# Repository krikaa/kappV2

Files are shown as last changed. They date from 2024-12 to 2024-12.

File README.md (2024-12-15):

# Nutika laborikapi edasiarendus 

Continuation of development of a smart metal locker module, to make it openable with an ISIC card or through a web application.

Continuation by (TalTech Computers and Systems project 2024):

* Kristjan Kaal
* Daniel Erg 
* Hendrik Haabu

[Original 2023 project](https://github.com/siimtishler/kapp) by (TalTech Computers and Systems project 2023):

* Markus Visnapuu 
* Rannar Randmäe 
* Siim Tišler
* Markus Veersoo

## Full documentation (in Estonian)

[Targa laborikapi edasiarendus aruanne.pdf](https://github.com/krikaa/kappV2/blob/master/Targa%20laborikapi%20edasiarendus%20aruanne.pdf) \
The documentation contains details about the improvements, description of the product and instructions on how it should be put together.

## Introduction
This is the repo for course "IAS1420 Arvutite ja süsteemide projekt" at TalTech 2023. 
The goal of the project was to fix some software issues regarding the 2023 year project, add support for multiple lockers and put all the hardware in a single module that is both simpler to install and more universal.
This repo is only for more convenient code management and project is intended only as a study project.

## Hardware
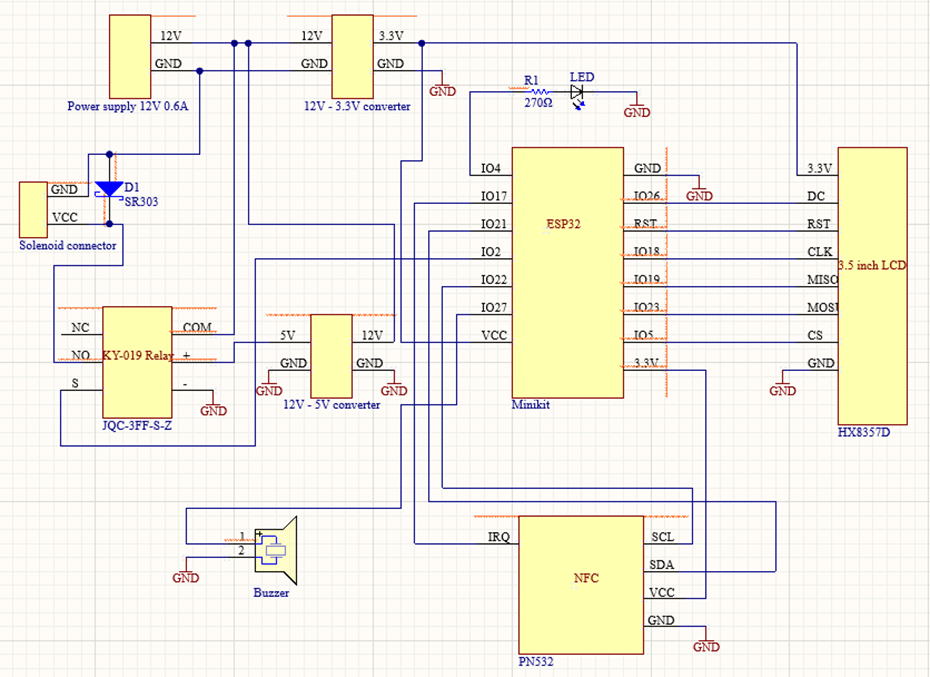
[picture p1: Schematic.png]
Schematic


## Installation
For fully setting up the device, the following has to be done:

1. Set up the web app:
* Clone the [web-interface](https://github.com/krikaa/kappV2-web-interface) submodule. 
* Set up a Google firebase with email-password user authentication and real-time database. 
* Add the rules found in database.rules.json to the Firebase database access rules. 
* Duplicate example.env, rename it to .env and fill the file in with the environment variables from your Firebase.
* Host the website on Firebase 
* Make the first admin account from Firebases management screen. 

2. Set up the electronics:
* Clone the [door-controller](https://github.com/krikaa/kappV2-door-controller/) submodule.
* Open the code in vscode and wait until necessary third-party libraries are installed through PlatformIO
* Duplicate FirebaseConfig.example.h, rename it to FirebaseConfig.h, and fill it in with your locker, Wi-Fi and Firebase details.
* Change PinConfig.h and platformio.ini to fit your hardware if necessary.
* Flash the code onto an ESP32.
* Build the [circuit](https://github.com/krikaa/kappV2/blob/master/Schematic.png) and test if everything works.

3. Set up the module:
* Print or manufacture the models found in the [3D-models](https://github.com/krikaa/kappV2/tree/master/3D-models) folder. 
NB! Be aware that many pieces require to be out of metal, or they will break!
* Put the module together by the instructions in the [documentation](https://github.com/krikaa/kappV2/blob/master/Targa%20laborikapi%20edasiarendus%20aruanne.pdf).
* Install the module on a locker by the instructions.

## Technologies Used
* C and C++ programming languages
* Firebase cloud service
* NFC reader library
* Visual Studio Code as an integrated development environment (IDE)
* SolidWorks for 3D CAD Design
* Git for version control

## Project layout/format
The project consists of two submodules:
* door-controller - Contains code for the ESP32 in the locker device, driving both the display and locking mechanism.
* web-interface - Contains code for the web interface, at https://nutikapp-v2.web.app

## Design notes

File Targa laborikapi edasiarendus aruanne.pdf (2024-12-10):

Tallinn 2024

TALLINNA TEHNIKAÜLIKOOL

Infotehnoloogia teaduskond

Daniel Erg 213407IACB
Hendrik Haabu 213440IACB
Kristjan Kaal 213423IACB

## Targa laborikapi edasiarendus

Arvutite ja süsteemide projekt

Juhendaja: Heiko Pikner

PhD

## Autorideklaratsioon

Kinnitame, et oleme koostanud antud projekti iseseisvalt ning seda ei ole kellegi teise

poolt varem kaitsmisele esitatud. Kõik töö koostamisel kasutatud teiste autorite tööd,

olulised seisukohad, kirjandusallikatest ja mujalt pärinevad andmed on töös viidatud.

Autorid: Daniel Erg, Hendrik Haabu, Kristjan Kaal

10.12.2024

## Lühendite ja mõistete sõnastik

RTOS | Real-time operating system, reaalaja operatsioonisüsteem
GPIO | General Purpose Input Output, üldkasutatav sisend-/väljundviik
JSON | JavaScript Object Notation, andmevahetusvorming
SPI | Serial Peripheral Interface, sünkroonse järjestiksuhtluse liidese standard
Wi-Fi | Sertifitseeritud IEEE 802.11 (https://et.wikipedia.org/wiki/IEEE_802.11) standardil põhinevad traadita kohtvõrgu klassi kuuluvad seadmed
NFC | Near-field communication, kontaktivaba lähiväljasidetehnoloogia
NO | Normally open, "tavapäraselt avatud“ väljaviik
SPA | Single-page application, üheleherakendus
HTML | Hypertext Markup Language, veebilehtede märgenduskeel
CSS | Cascading Style Sheets, küljendamisel kasutatav märgistuskeel
URL | Uniform recource locator, internetiaadress
SSID | Set Service Identifier, võrgu nimi traadita võrgus

## Sisukord

## Jooniste loetelu

Joonis 2. Nutikapi mooduli prototüüp paigaldatud esimesele laborikapi variandile...... 10

Joonis 10. Gerd Kanter Hoidiku sees ja fikseerimas Käepidet Ekraanikorpuse külge. . 15

Joonis 15. Käepide koos postkastiluku komplektiga ning tugipunkt Elektroonikakarbis

Joonis 17. Solenoid Elektroonikakarbis ning Käepideme ja keele asend kui kapp on

Joonis 29. Käepideme 90° liikumisulatuse funktsioon Gerd Kanteri ja Kimalase vahel.

Joonis 34. „BasicNavBar.vue“ administraatori vaates erinevate aknasuuruste puhul ... 38

Joonis 40. Ava Ekraanikorpusest tulevate juhtmete jaoks ning prototüüp koos juhtmega.

Joonis 41. Prototüübiks kasutuses olnud Käepide ja esimese valmis komponendi jaoks

Joonis 43. Detailid kolmanda valmis komponendi jaoks ning pistikud Elektroonikakarbi

Joonis 45. Ühe testitud laborikapi jaoks vajaminevad Tuulerõuged mooduli

## 1 Sissejuhatus

Käesolev töö on edasiarendus targa laborikapi projektist [1]. Tallinna Tehnikaülikoolis

on laialdaselt kasutusel erinevat tüüpi laborikapid ja nii mõnelegi on soovitud paigaldada

tark süsteem. Kuna NFC-l põhinevate lukusüsteemide kasutamise populaarsus on ajaga

suurenenud, siis on teema aktuaalne [2].

Projekti ülesanne on arendada edasi varem tehtud tarka laborikappi. Eelneva töö

puudusteks olid tarkvaras mitme kapi toe puudumine ja lahenduse realisatsioon mitme

moodulina ehk mitme füüsilise tükina, mis muutis paigaldamise tülikaks, ja kapi

originaalse riivi eemaldamise vajadus. Eelneva targa laborikapiga oli ka see probleem, et

ühel hetkel seda ei saanud enam kaardiga avada ja mure oli ka see, et kui vool ära kadus,

siis oli kapi avamine samuti üsna ebamugav. Seega antud töö eesmärk on ehitada

võimalikult kompaktne, soodne, universaalne ja lihtsasti paigaldatav moodul, mis

muudaks metallist laborikapi targaks, kusjuures tarkvara peab võimaldama mitme kapi

kasutust. Lahendus peab kasutama ka kapi originaalset riivi ja voolu kadumisel peab kapp

olema avatav ka võtmega. Eesmärk on muuta ka kapp jälle kaardiga avatavaks.

Töö hõlmab endas nii riistvara, tarkvara, mehaanikat kui ka modelleerimist. Terve

projekti vältel tegeleti nende kõikide mainitud osadega pidevalt, kuid alguses oli suurem

rõhk modelleerimisel ja riistvaral. Töö peatükid on jaotatud samasugusel põhimõttel:

alguses selgitatakse lukusüsteemi kogu mehaanika ja modelleerimisega seonduvat poolt,

siis selgitatakse riistvara kasutust ja elektriskeemi ning lõpuks mõtestatakse lahti

tarkvaraline osa, sealhulgas püsivara ja veebirakendus. Viimasteks peatükkideks on

mooduli paigaldamise juhend ja edasiarenduse võimalused.

## 2 Mehaanika

Nutikapi mooduli loomiseks modelleeriti esialgu prototüüp ning hiljem lõplik toode.

Prototüüp prinditi plastikust ning seda kasutati kahel erineval laborikapil testimiseks.

Katsete käigus tuvastatud puudujääkide tõttu tuli muuta nii detailide mõõtmeid kui ka

modelleerida osad mudelid ümber eesmärgiga need hiljem metallist toota, sest need ei

pidanud kapi hoovamehhanismi liigutades pingele vastu. Prototüübi peatükk kirjeldab

esialgse mooduli jaoks ehitatud detaile, nende probleeme ja funktsionaalsust ning lõpliku

mooduli peatükis on välja toodud muudatused toote viimase versioonini jõudmiseks.

Kõik detailid on modelleeritud 3D projekteerimistarkvaras Solidworks.

### 2.1 Prototüüp

Prototüübi jaoks modelleeriti 9 detaili, mille nimed on Ekraanikorpus, Ekraanikorpuse

Kaas, Käepide, IKEA Laud, Gerd Kanter, Hoidik, Naagelvärk, Elektroonikakarp ja

Elektroonikakarbi Kaas.

Lisaks soetati ehitusmaterjali poodidest M1x10 mm, M3x16 mm ja M4x90 mm suurusega

polte, 3.5x9.5 mm suurusega kruvisid, 3/4 tolli suurusega kontramutter ja pikkvint,

nelinurkne M4 mutter, M4 suurusega võllikrae ja postkastiluku komplekt.

Joonisel 1 on näha prototüübi modelleeritud detailid kokkupanduna ning joonistel 2 ja 3

on näha prototüübi paigaldust kahele laborikapi variandile.

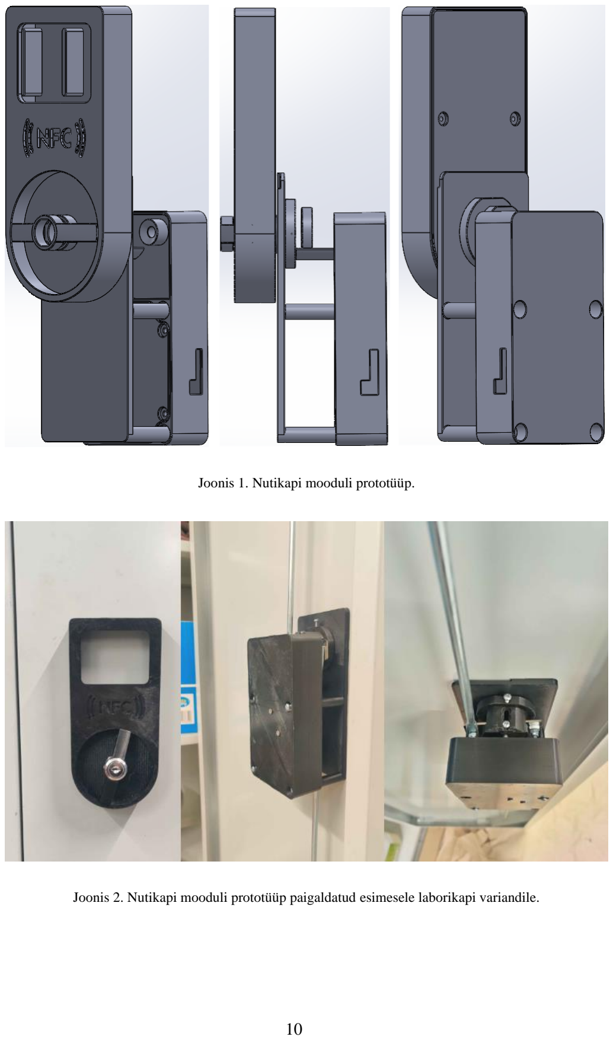
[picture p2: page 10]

Joonis 1. Nutikapi mooduli prototüüp.

Joonis 2. Nutikapi mooduli prototüüp paigaldatud esimesele laborikapi variandile.

Joonis 3. Nutikapi mooduli prototüüp paigaldatud teisele laborikapi variandile.

### 2.1.1 Mooduli väline korpus

Mooduli väline korpus on laborikapist väljapoole jääv ekraani ja NFC moodulit hoiustav

komponent (vt Joonis 2 ja 3, vasakpoolne pilt). See koosneb modelleeritud Käepidemest,

Ekraanikorpusest ja Ekraanikorpuse Kaanest ning ehitusmaterjalide poest soetatud

postkastilukust, kolmest 3.5x9.5 mm suurusega kruvist ja 3/4 tolli suurusega pikkvindist.

Joonisel 4 on näha välise korpuse mudeleid nii eest kui ka tagant.

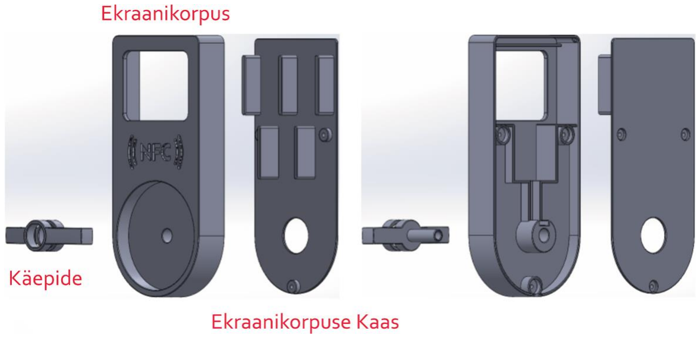
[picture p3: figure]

Joonis 4. Mooduli välise korpuse detailid.

Ekraanikorpuse sees olev suurem ristkülikukujuline süvend on mõeldud puutetundliku

ekraani jaoks ning väiksem NFC mooduli jaoks. Korpuse kaanel on viis väljaulatuvat

risttahukat, mille eesmärgiks on hoida ekraani ja NFC moodulit korpuse vastas. Kaanel on ka kolm silindrikujulist jalga, mis sobituvad korpusel olevatesse analoogsetesse

süvenditesse ning need kinnitatakse väljastpoolt kolme 3.5x9.5 mm suuruse kruviga.

Joonisel 4 vasakult teisel detailil ehk Ekraanikorpusel on ka näha ringikujulist süvendit,

mis on mõeldud Käepideme pöörlemiseks ning NFC logo, mille mudel on võetud eelmise

laborikapi mooduli versiooni tegijatelt [1]. Käepideme toru ulatub läbi Ekraanikorpuse

kapi sisse.

### 2.1.2 Mooduli kinnitus kapi uksele

Mooduli kinnitus kapi uksele on kapist sissepoole jääv komponent, mille eesmärk on

hoida Ekraanikorpust ja Elektroonikakarpi kapi ukse küljes. See koosneb modelleeritud

IKEA Lauast ning selle juures mängib olulist rolli ka Ekraanikorpuse tagant väljaulatuv

jäme silinder. Lisaks on kasutusel 3/4 tolline kontramutter ja pikkvint ning neli M3x16

mm polti. Joonisel 5 on näha kinnituse modelleeritud detailid.

Joonis 5. Mooduli kinnituse detailid.

IKEA Laua jalgade külge kinnitub Elektroonikakarp ning seda hoiavad jalgade küljes neli

M3x16 mm polti. Laud jääb Ekraanikorpusest allapoole, kuna mõlemal testitud

laborikapil jäi sisemine riiul muidu Elektroonikakarbile ette. Ekraanikorpuse ja IKEA

Laua vahele jääb laborikapi uks. Eemaldades ukse originaalse käepideme, jääb selle

asemele ava ning läbi ava ja IKEA Laual oleva suure ümmarguse augu paigaldatakse

Ekraanikorpus tänu tema küljes olevale jämedale silindrile. Prototüübi testimiseks saeti

3/4 tolline pikkvint sobivaks suuruseks ning kinnitati silindri ümber, mistõttu sai

kontramutri abil suruda IKEA Laua ja Ekraanikorpuse tugevalt ukse külge (vt Joonis 6).

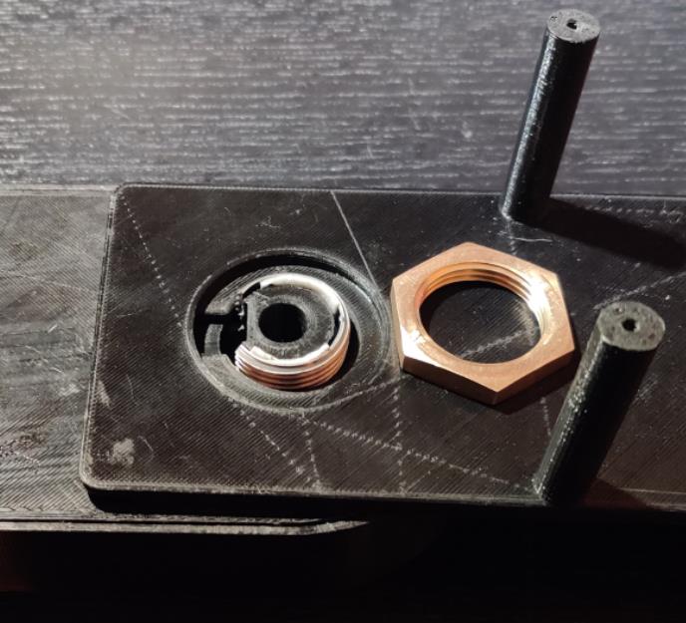
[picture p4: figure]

Joonis 6. Pikkvint Ekraanikorpuse silindri küljes.

### 2.1.3 Elektroonikakarp

Elektroonikakarp on IKEA Laua külge kinnituv solenoidi ja elektriskeemi hoiustav

komponent, mis koosneb modelleeritud karbist ja selle kaanest (vt Joonis 7). Kaane

kinnitamiseks on kasutusel neli 3.5x9.5 mm kruvi.

Joonis 7. Elektroonikakarbi detailid.

Elektroonikakarbi külje peal on avad 12 V toitepistiku ning ekraani ja NFC mooduli

küljest tuleva 15 viiguga juhtme pistiku jaoks. Karbi üleval servas oleva silindri ning

solenoidi täpsema asetuse ja eesmärgi kohta on kirjas kapi lukustamise mehhanismi

alapeatükis.

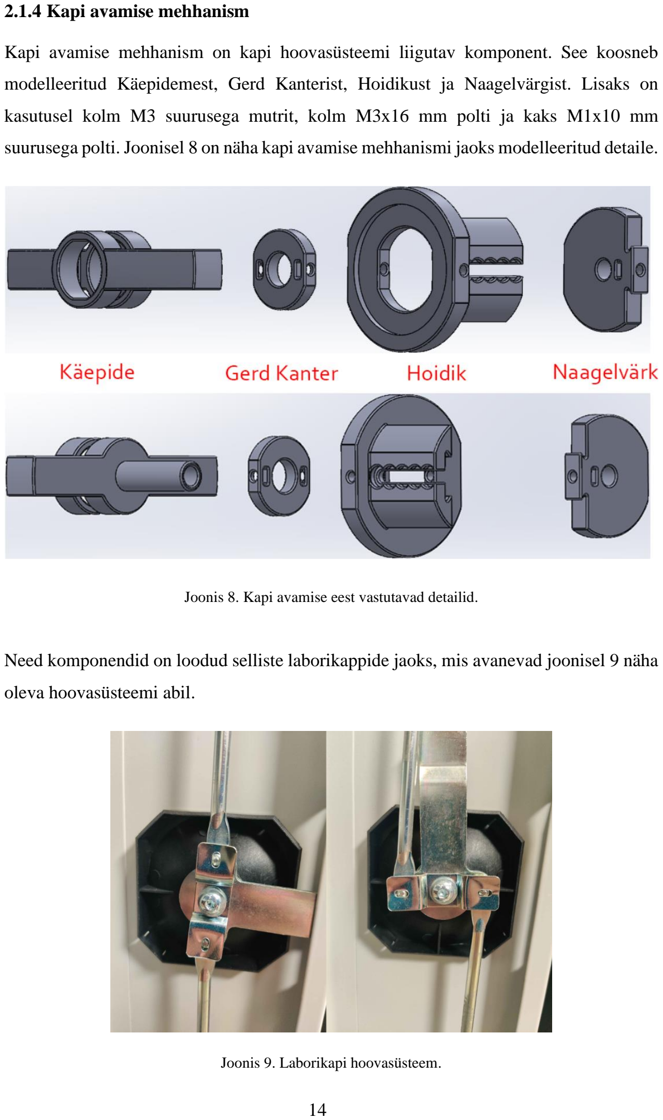
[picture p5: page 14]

### 2.1.4 Kapi avamise mehhanism

Kapi avamise mehhanism on kapi hoovasüsteemi liigutav komponent. See koosneb

modelleeritud Käepidemest, Gerd Kanterist, Hoidikust ja Naagelvärgist. Lisaks on

kasutusel kolm M3 suurusega mutrit, kolm M3x16 mm polti ja kaks M1x10 mm

suurusega polti. Joonisel 8 on näha kapi avamise mehhanismi jaoks modelleeritud detaile.

Joonis 8. Kapi avamise eest vastutavad detailid.

Need komponendid on loodud selliste laborikappide jaoks, mis avanevad joonisel 9 näha

oleva hoovasüsteemi abil.

Joonis 9. Laborikapi hoovasüsteem.

Gerd Kanter kinnitub kahe M1x10 mm suuruse poldiga Käepideme toru külge ja kahe

M3x16 mm poldiga Hoidiku külge. Tema küljes olevate piklike avade sisse kinnitati

eraldi M3 mutrid, mis olid mõeldud ajutiste keermetena. Gerd Kanteri eesmärk on keerata

Hoidikut ning vältida Käepideme välja kukkumist Ekraanikorpusest (vt Joonis 10).

Joonis 10. Gerd Kanter Hoidiku sees ja fikseerimas Käepidet Ekraanikorpuse külge.

Hoidiku eesmärk on keerata laborikapi hoovasüsteemi ning sellele kinnitati Naagelvärk

ühe pooleks saetud M3x16 mm poldiga hoovasüsteemi paremaks fikseerimiseks (vt

Joonis 11).

Joonis 11. Hoovasüsteem Hoidiku ja Naagelvärgi vahel.

Hoidiku all on viis erinevat süvendit M3x16 mm poldi kinnitamiseks. Nende abil on

võimalik Naagelvärgi kaugust kapi hoovasüsteemist reguleerida, kuna erinevatel

laborikappidel võib süsteem olla kas teistsuguse kujuga või asetseda kapi seinast

kaugemal või lähemal. Ka Naagelvärgile oli prototüübi jaoks modelleeritud piklik auk

ajutise mutri kinnitamiseks. Hoidikut ja Naagelvärki altvaates on näha joonisel 12.

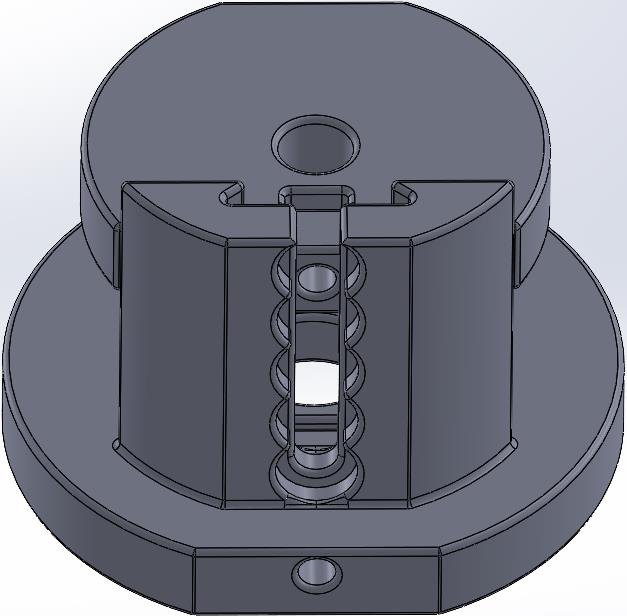
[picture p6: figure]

Joonis 12. Hoidik ja Naagelvärk altvaates.

Kinnises asendis toimivad kapi hoovasüsteemist välja ulatuvad pikad vardad riividena

ning hoiavad ust kapi ülemise ja alumise serva küljes kinni. Keerates käepidet 90°

päripäeva, liigutab Hoidik hoovasüsteemi lahtisesse asendisse ning kapp avaneb.

Hoovasüsteem kinnises asendis on näha joonisel 13 vasakul pool ja lahtises asendis

paremal pool.

Joonis 13. Kapi avamise liigutus.

Kapi sulgemiseks tuleb keerata käepidet tagasi 90° vastupäeva.

### 2.1.5 Kapi lukustamise mehhanism

Kapi lukustamise mehhanism on kapi ukse lukustamise loogikat käsitlev komponent.

Lisaks avamise mehhanismi komponendile, koosneb lukustamise komponent

postkastiluku komplektist, ühest M4x90 mm poldist ning võllikraest, nelinurksest mutrist

ja seibist, mis on kõik M4 suurusega. Riistvarast on kapi lukustamisel oluline roll

solenoidil ja NFC moodulil.

Pannes kõik siiamaani käsitletud komponendid tagasi kokku, on märgata, et läbi kogu

mooduli on jäetud 6 mm diameetriga ava (vt Joonis 14, sinine täpp).

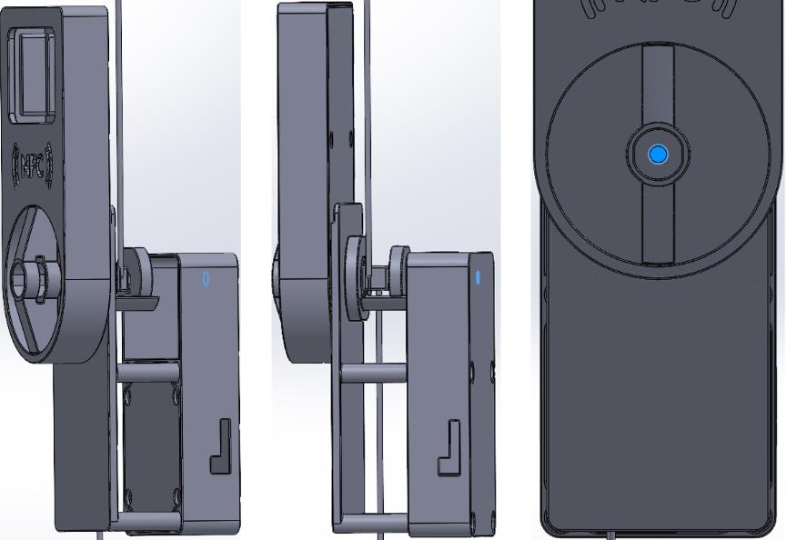
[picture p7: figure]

Joonis 14. Nutikapi moodulit läbiv ava.

Kogu ava läbib M4x90 mm polt, mis on ühe otsaga kinnitatud Käepideme sees oleva

postkastiluku külge ja teine ots toetub Elektroonikakarbi üleval servas oleva jämeda

silindri sisse (vt Joonis 15).

Joonis 15. Käepide koos postkastiluku komplektiga ning tugipunkt Elektroonikakarbis

Poldil on Elektroonikakarbi poolsel otsal keermed maha lihvitud ning teisel pool pea ära

lõigatud. Lihvitud otsale puuriti tilluke süvend, millesse kinnitati esimesena väikse

kruviga võllikrae ja teiseks postkastiluku keel, mille sees on sobivaks suuruseks lihvitud

nelinurkne mutter eesmärgiga kanda jõudu Käepidemelt keelele. Järgmisena kinnitati

poldile seib, mis hoiab keelt võllikrae vastas ning lõpus liimiti detailid tugeva kiirliimiga

kokku (vt Joonis 16).

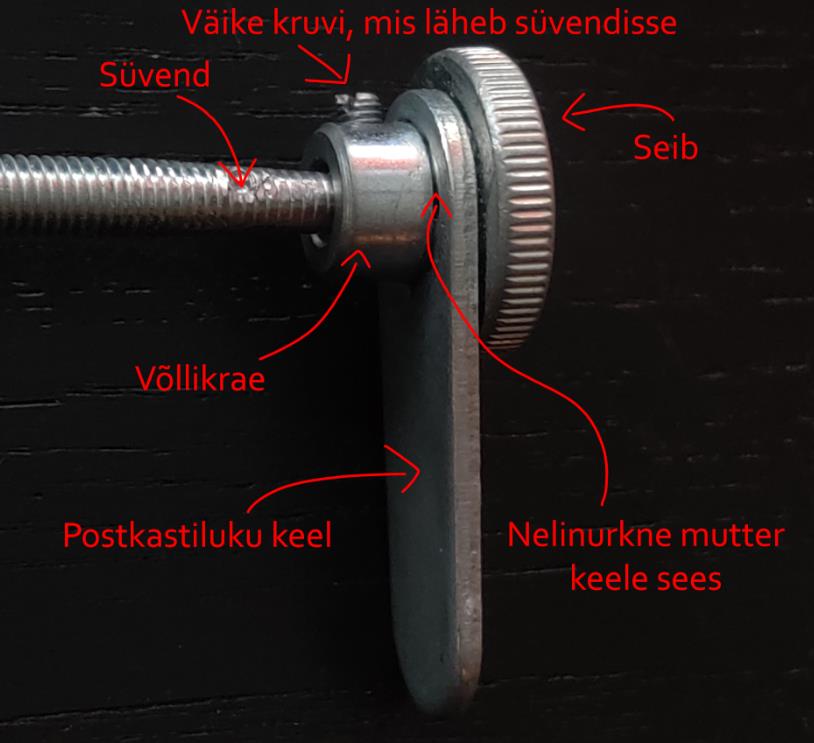
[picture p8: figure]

Joonis 16. Postkastiluku keele kinnitus poldi otsas.

Kuna postkastiluku keel on Käepideme küljes, ongi tema eesmärgiks lukustada kapp ehk

blokeerida Käepideme liikumine. Keele liikumise takistamiseks on kasutusel solenoid.

Joonisel 17 on näha solenoidi asukoht Elektroonikakarbis ning Käepideme ja keele asend

kui kapp on lukustatud.

Joonis 17. Solenoid Elektroonikakarbis ning Käepideme ja keele asend kui kapp on lukustatud.

Kuna kapi hoovasüsteemi liigutamiseks avatud asendisse tuleb käepide keerata 90°

päripäeva, on see hetkel piiratud, sest solenoid takistab keele liikumist. Selleks, et

Käepide liigutada, on esimeseks variandiks asetada ISIC kaart NFC mooduli vastu,

mistõttu läheb solenoidi keel alla ja Käepide on võimalik keerata. Prototüübil on võimalik

keerata ka Käepide täisnurga võrra vastupäeva, kuid lõplikul tootel on see takistatud. Kapi

lukustamiseks tuleb Käepide keerata tagasi 90° vastupäeva ning postkastiluku keel liigub

sujuvalt üle solenoidi keele ja jõuab tagasi suletud asendisse (vt Joonis 18).

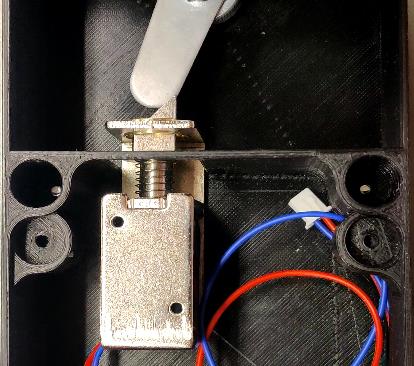
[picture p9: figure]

Joonis 18. Postkastiluku keele liikumine üle solenoidi keele.

Teine variant kapi avamiseks on keerata võtmega postkastilukku. Sellisel juhul pöörleb

keel 90° vastupäeva, mistõttu on võimalik taaskord Käepidet keerata täisnurga võrra

päripäeva (vt Joonis 19).

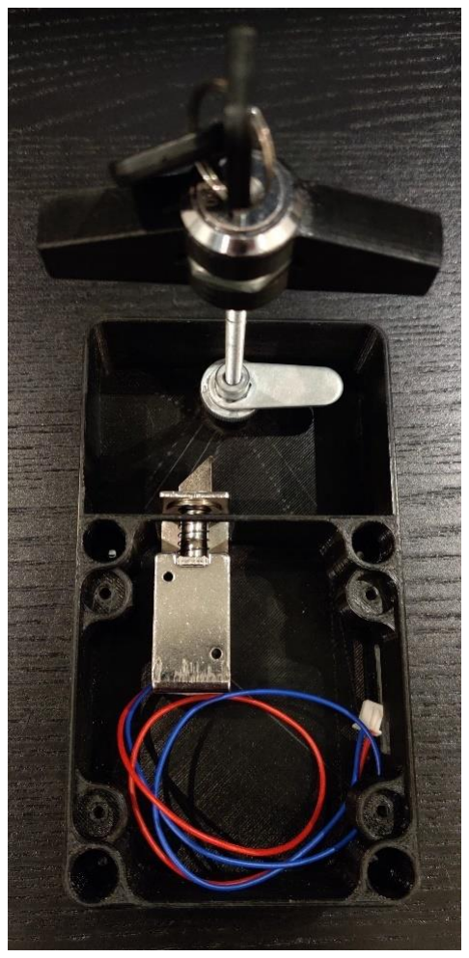
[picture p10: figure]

Joonis 19. Keele keeramine võtmega 90° võrra vastupäeva.

Kuna Käepidemest väljaulatuv polt pole kuidagi ühendatud Gerd Kanteri, Hoidiku ega

hoovasüsteemiga ning saab neid läbides vabalt pöörelda, siis võtmega poldi ja keele

keeramine ei liiguta Hoidikut ega Käepidet.

### 2.2 Lõplik moodul

Prototüübi testimisel laborikappidel oli põhiliseks probleemiks plastikdetailide nõrkus –

hoovasüsteemi liigutavad ja moodulit kapi küljes hoidvad komponendid läksid mõõduka

pinge all katki. Lisaks tuli muuta mõnde komponenti mõõtmeid. Seetõttu otsustati

modelleerida osad detailid eesmärgiga need lõpuks metallist toota ning mõelda välja

viisid, kuidas need plastikdetailide külge kinnitada. Kuna puudus metalliprinter, ei olnud

võimalik uusi komponente toota, mistõttu neid ei testitud kordagi laborikappidel.

Lõplik toode koosneb 12 modelleeritud detailist nimedega Ekraanikorpus,

Ekraanikorpuse Kaas, Kimalane, Käepide, Toru, IKEA Laud, Mutter, Gerd Kanter,

Hoidik, Naagelvärk, Elektroonikakarp ja Elektroonikakarbi Kaas.

Kimalane, Toru, Mutter, Gerd Kanter, Hoidik ja Naagelvärk on mõeldud tootmiseks

metallist, ülejäänud plastikust.

Joonis 20. Targa laborikapi mooduli lõppversioon.

### 2.2.1 Mooduli välise korpuse muudatused

Uue mooduli väline korpus koosneb lisaks Käepidemele, Ekraanikorpusele ja

Ekraanikorpuse Kaanele ka Kimalasest ning Torust. Kimalane on metallist detail, mis

asendab prototüübil olnud jämeda silindri ning eraldi pikkvindist saetud keermed. Toru

on metallist detail, mis asendab eelneva Käepideme plastikust toru. Lisaks muudeti

ekraaniava suurust, kuna vahepeal võeti kasutusele uus ekraanimoodul, ning korpusele

lisati juurde Tuulerõuged ehk üheksa M3 poldi süvendit, millest on täpsemalt kirjas

mooduli kapile paigaldamise peatükis. Joonisel 21 on näha paarides vastavalt uut ja vana

korpust.

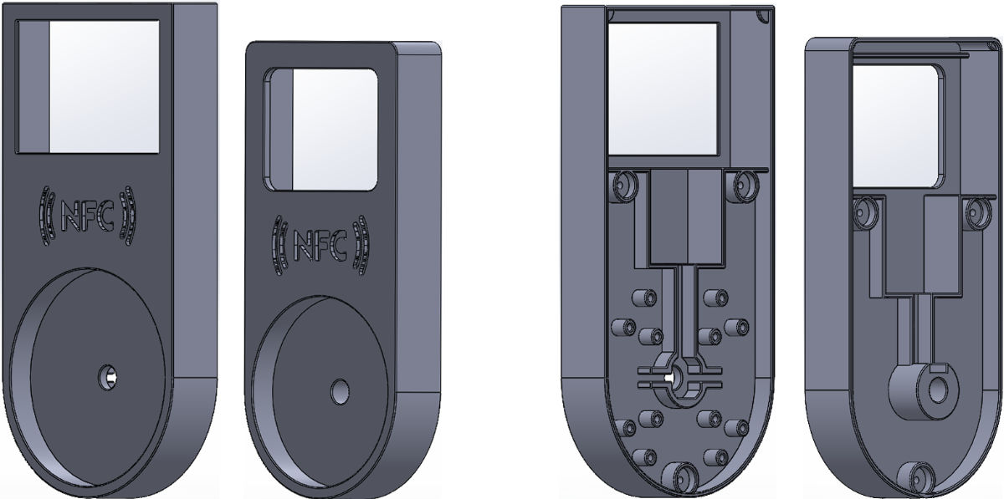
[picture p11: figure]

Joonis 21. Uue ja vana Ekraanikorpuse võrdlus eest ja tagant.

Kuna uus ekraan oli pikema diagonaaliga, muudeti kogu korpust suuremaks. Lisaks on

tagant näha, kuidas jäme silinder on asendatud uue Kimalase pesaga. Kimalast ning selle

asetsemist süvendis on näha joonisel 22.

Joonis 22. Kimalane ja selle asetsemine Ekraanikorpuse süvendis.

Kimalane kinnitub süvendisse kahe M3x16 mm poldiga ning tema tööpõhimõte on

täpsemalt lahti seletatud mooduli uuendatud kinnituse ja uuendatud kapi avamise

mehhanismi alapeatükkides.

Kuna eelmine plastikust Käepideme toru läks esimesena prototüübi testimisel pooleks,

asendati see eraldi metallist detailiga, mida on koos uue Käepideme mudeliga näha

joonisel 23.

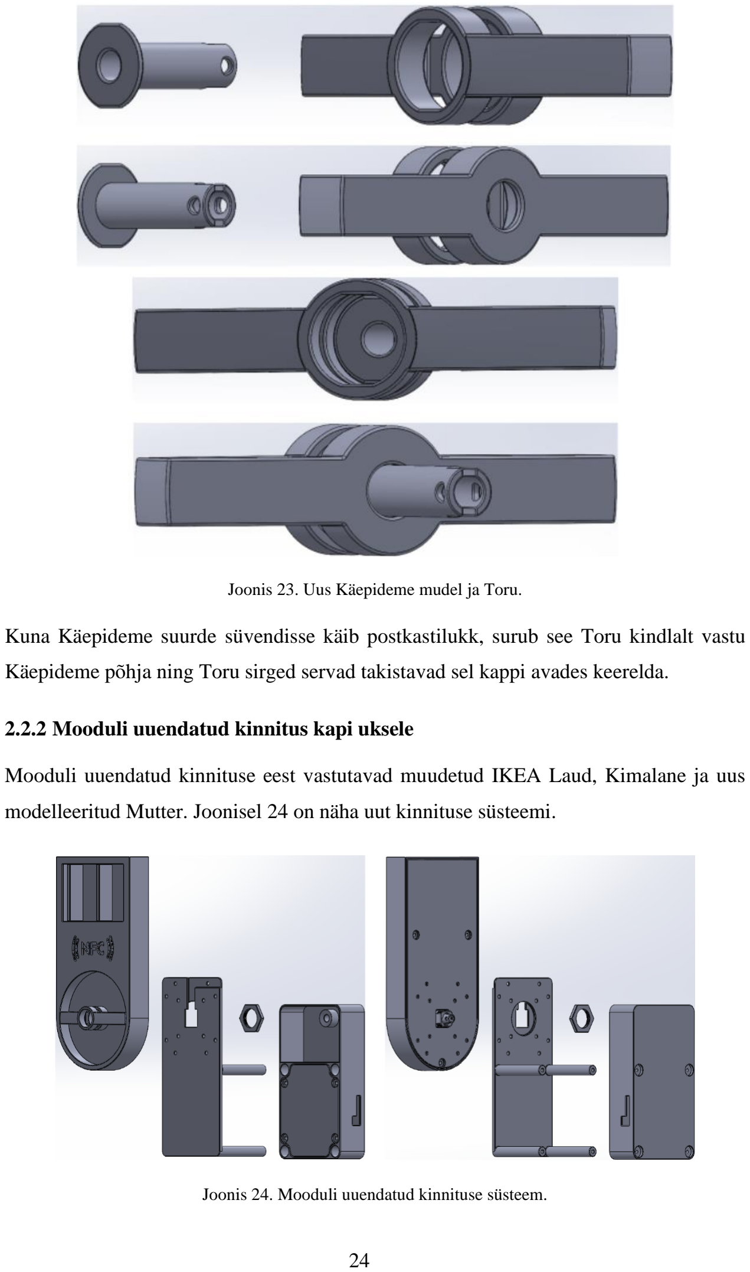
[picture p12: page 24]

Joonis 23. Uus Käepideme mudel ja Toru.

Kuna Käepideme suurde süvendisse käib postkastilukk, surub see Toru kindlalt vastu

Käepideme põhja ning Toru sirged servad takistavad sel kappi avades keerelda.

### 2.2.2 Mooduli uuendatud kinnitus kapi uksele

Mooduli uuendatud kinnituse eest vastutavad muudetud IKEA Laud, Kimalane ja uus

modelleeritud Mutter. Joonisel 24 on näha uut kinnituse süsteemi.

Joonis 24. Mooduli uuendatud kinnituse süsteem.

Peamine erinevus vana süsteemiga on IKEA Lauale lisandunud Tuulerõuged, mis on ka

Ekraanikorpuse Kaanel, ning Laua suure ava kuju muutmine ristkülikukujuliseks. Kuna

vana Ekraanikorpuse jämedat silindrit asendab nüüd Kimalane, mis on samuti

ruudukujuline, püsib mooduli kapisisene osa alati välise korpusega paralleelselt. Lähemat

vaadet Kimalase kinnitumisest IKEA Laua külge on näha joonisel 25.

Joonis 25. Kimalase kinnitumine IKEA Laua külge.

Lisaks modelleeriti juurde spetsiaalselt nutikapi moodulile sobiv Mutter, kuna

ehitusmaterjalide poest sobivat mutrit ei leitud.

### 2.2.3 Elektroonikakarbi muudatused

Elektroonikakarpi muudeti lõplikus moodulis võrreldes teiste komponentidega väga

vähe. Vähendati karbi taga olevate kruvisüvendite sügavust ning tehti postkastiluku poldi

tugipunkti silindrit sügavamaks. Vana ja uue elektroonikakarbi erinevused on näha

joonisel 26.

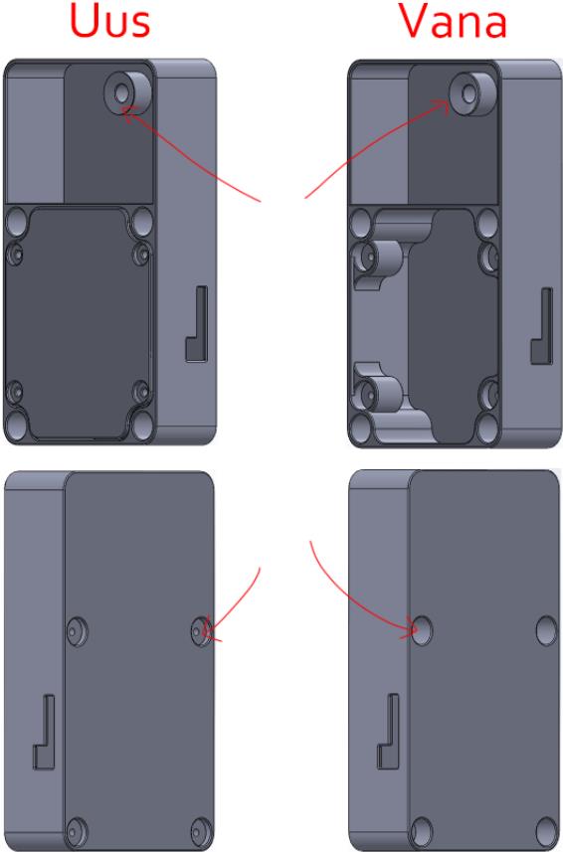
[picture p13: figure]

Joonis 26. Elektroonikakarbi muudatused.

### 2.2.4 Uuendatud kapi avamise mehhanism

Enamik muudatusi võrreldes prototüübi detailidega tehti kapi avamise mehhanismi

juures. Uus mehhanism koosneb Käepidemest, Torust, Kimalasest, Gerd Kanterist,

Hoidikust ja Naagelvärgist. Esiteks on iga mudel nüüd mõeldud tootmiseks metallist,

teiseks muudeti iga detaili kuju ja suurust ning kolmandaks mängib olulist rolli kapi

avamisel ka Kimalane.

Joonis 27. Kapi uuendatud avamise mehhanismi detailid.

Hoidik ja Naagelvärk jäid põhimõtteliselt samasuguseks. Naagelvärgil eemaldati ajutine

auk mutri jaoks ning muudeti veidike nii Naagelvärgi kui ka Hoidiku kuju ja suurust.

Peamine muudatus on Toru kinnitumine Gerd Kanteri külge ning uus Käepideme 90°

liikumisulatuse funktsioon Gerd Kanteri ja Kimalase vahel. Prototüübil oli Käepideme

toru kinnitatud Gerdi külge kahe M1x10 mm poldiga, kuid need olid liiga peenikesed

ning läksid hoovamehhanismi keerates lõpuks pooleks. Uuel Kanteril on kaks M3 kruvi

auku ning külgede peale on jäetud süvendid, et kruvi pead mahuksid Hoidiku alla.

Joonisel 28 on näha Toru, Gerd Kanterit ja Hoidikut kokku ühendatuna.

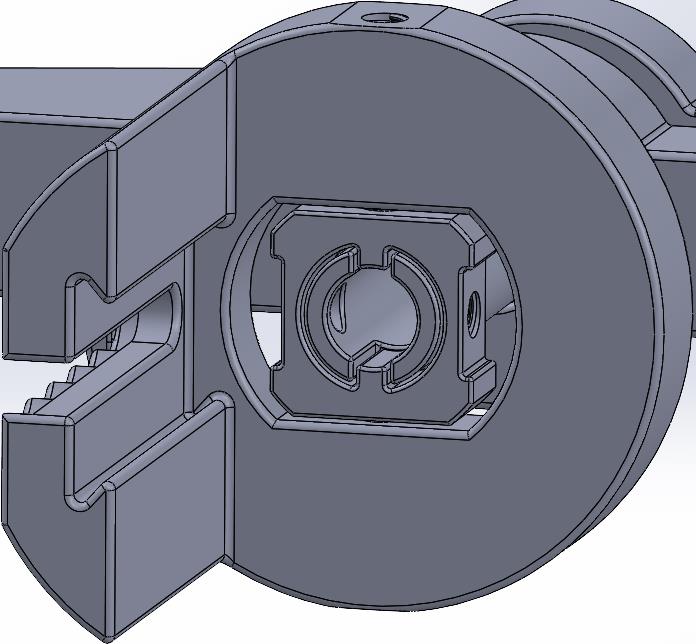
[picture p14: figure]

Joonis 28. Toru, Gerd Kanter ja Hoidik kokku ühendatuna.

Uue Gerd Kanteri ja Kimalase vahelise 90° Käepideme liikumisulatuse funktsiooni jaoks

modelleeriti Gerdile väike vars, mis libiseb Kimalases oleva kaare sees (vt Joonis 29,

sinised märgistused).

Joonis 29. Käepideme 90° liikumisulatuse funktsioon Gerd Kanteri ja Kimalase vahel.

### 2.2.5 Kapi lukustamise mehhanismi muudatused

Analoogselt Elektroonikakarbi komponendiga, ei muudetud eriti palju kapi lukustamise

mehhanismi, kuna see töötas vigadeta. Ainus muudatus oli käepidemes postkastiluku

mutri augu läbimõõdu suurendamine, kuna prototüübi mudelil oli see liiga väike ning

seda tuli käsitsi suuremaks lihvida.

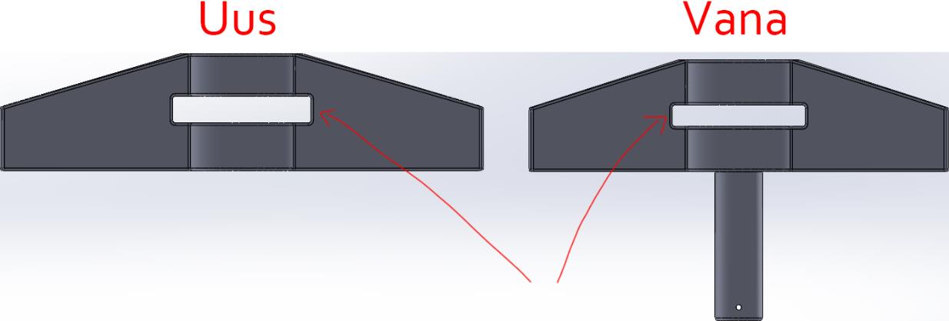
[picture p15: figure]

Joonis 30. Postkastiluku mutri augu suurendus võrreldes prototüübiga.

## 3 Riistvara

Lahenduse realisatsioon hõlmab endas järgnevat riistvara:

- ESP32 minikit mikrokontroller,
- 12 V 1.2 A toiteplokk,
- D-sun 4R7 1136 pinge regulaator,
- S7V7F5 pinge regulaator,
- SR303 Schottky diood,
- 12 V LKmini08 solenoidlukk,
- KY-019 JQC-3FF-S-Z releemoodul,
- KSSG1201-16 sumisti,
- 270 Ω takisti,
- Punane LED,
- PN532 v3 NFC moodul,
- 3.5-tolline Adafruit HX8357D LCD ekraan.

Võrreldes eelmise projektiga, on juurde tulnud ESP32 minikit mikrokontroller kahe

ESP8266 D1 mini asemele. ESP8266 D1 mini puuduseks on ühetuumalisus ja ka GPIO

väljaviikude vähesus ja eelnevalt nimetatud ESP32 mikrokontroller lahendab mõlemad

probleemid. See valik muutis kogu lahenduse kompaktsemaks, mis oli ühtlasi üks töö

eesmärkidest.

Kasutusele on tulnud ka solenoidi jaoks kaitsediood SR303. Voolu kadumisel solenoidi

polaarsus muutub vastupidiseks, mistõttu tekib suur tagasilöögipinge ja ilma kaitsmeta

pikema aja jooksul põletaks see ära relee ja solenoidi vahelise kontakti. Kaitsedioodi

olemasolul voolu kadumisel saab solenoid ennast korralikult tühjaks laadida [3]. Dioodi

mudeli valik on tehtud selle põhjal, et vastupingestatud olekus see ei juhiks voolu [4].

Solenoid saab 12 V toidet ja antud diood vajab vastupingestatult vähemalt 21 V pinget,

et see hakkaks voolu juhtima [5].

Lahenduses on kasutusel ka teistsugune releemoodul. Sellele ei ole lisatud eraldi

kaitsedioodi, sest antud moodulil on juba kaitsediood olemas.

Juurde on tulnud ka veel üks pinge regulaator. ESP32 mikrokontroller vajab 3.3 V pinget

töötamiseks, kuid kasutusel olev releemoodul nõuab 5 V pinget, seega lõpuks oli vaja

kahte toite regulaatorit.

### 3.1 Elektriskeem

Lahenduse riistvaralisi komponente juhib ESP32 minikit mikrokontroller. Sellega on

ühendatud 3.3 V väljundiga toite regulaator, LED koos takistiga, releemoodul, sumisti,

NFC moodul ja LCD ekraan.

Kogu süsteemi toide on rahuldatud 12 V toiteplokiga, mille pinge muundavad ümber 5

voldiks ja 3.3 voldiks kaks pinge regulaatorit. 5 V pinget kasutab releemoodul, mis

omakorda lülitab 3.3-voldise loogikasignaali abil [6] toiteplokist tuleva 12 V pingega

solenoidlukku. Relee puhul on kasutusel NO väljaviik, sest solenoid peab

normaaltingimustel olema avatud.

Teise toite regulaatori väljundpinget kasutab mikrokontroller ja ekraan. Joonisel 31 on

näha, et NFC moodul kasutab enda toiteks mikrokontrollerist tulevat sama suurt pinget,

kuid tegelikult on ka võimalik seda toita sama toite regulaatori 3.3-voldise

väljundpingega. Visuaalse arusaadavuse huvides on see nii jäetud. NFC mooduliga

suhtlemiseks on kasutatud I2C protokolli ja kõik vajalikud ühendused on tehtud vastavalt

dokumentatsioonile [7]. Kasutusel on ka mooduli IRQ väljaviik, et kontroller ei peaks

pidevalt NFC moodulilt küsima, kas kaart on tuvastatud. Sedasi saadab kaardilugeja

lihtsalt teatesignaali juhtseadmele, kui kaart on skaneeritud.

Skeemis on ka perifeerse eesmärgiga sumisti ja punane LED. LEDile on lisatud üks 270

Ω takisti, et LED jääks pingega enda tööpiirkonda.

Algselt oli lahenduses kasutusel üks 3.2-tolline Raspberry Pi jaoks mõeldud LCD ekraan.

Draivereid, et see ESP32 peal tööle saada, aga ei olnud nii, et viimasel hetkel vahetati

ekraan 3.5-tollise Adafruit HX8357D LCD ekraani vastu välja. Viimast ekraani aga ei

jõutud katsetada, kuid skeem peaks teoreetiliselt töövõimeline olema.

Kommunikatsioon mikrokontrolleri ja ekraani vahel toimub läbi SPI protokolli.

Puutetundlikkuse tagamiseks on kasutatud resistiivse puuteekraani funktsionaalsust.

Sedasi on vajaminevate ekraani ja mikrokontrolleri vaheliste ühenduste hulk võimalikult

väike tänu millele on mooduli paigaldus natuke lihtsam ja tagatud on ka pisut suurem

töökindlus. | Täpsed | väljaviikude | ühendused | on | tehtud | vastavalt | esemete

dokumentatsioonidele [8] [9].

Joonis 31. Laborikapi elektriskeem.

## 4 Tarkvara

Edasiarenduse tarkvara jaguneb kaheks suuremaks osaks - mikrokontrolleri püsivaraks

ja veebiliidese tarkvaraks. Varasemas projektis hargnes püsivara veel omakorda kahe

mikrokontrolleri vahel. Ekraani juhtiva selli ja lukustussüsteemi juhtiva meistri asemel

võeti edasiarenduse raames kasutusele üks kahetuumaline ESP32, mis teeb paralleelselt

mõlema varasemalt kasutatud ESP8266 töö ära. See mitte ainult ei lihtsusta skeemi,

vaid on ka energiasäästlikum ja kiirem [10]. Kapi ja kasutajaliidese vaheliseks

suhtluseks kasutatakse ühist Google Firebase’i reaalaja andmebaasi [11]. Tarkvara

arendamise käigus kasutati vana projekti kiiremaks ja paremaks mõistmiseks suure

keelemudeli ChatGPT abi [12].

### 4.1 Andmemudel

Joonisel 32 on näha üldine graafiline ülesehitus JSON andmemudelist. Andmemudelis on

enamasti säilinud samad väljad, mis varasemas projektis. Kuna mooduli universaalseks

muutmise käigus loobuti magnetsensori kasutamisest, on vastavad väljad andmemudelist

eemaldatud. Mitme kapi toe lisamiseks tuli mudelile teha mõningaid muudatusi

olemitevahelistes suhetes, muutes puu sügavamaks. Lisandunud on uus haru users, et

lisada tugi veebirakenduse ligipääsu haldamiseks. Andmepuu juurest väljuvad tipud users

ja lockers, mis eraldavad kahte rakenduse põhiosa: veebi- ja kapikasutajaid.

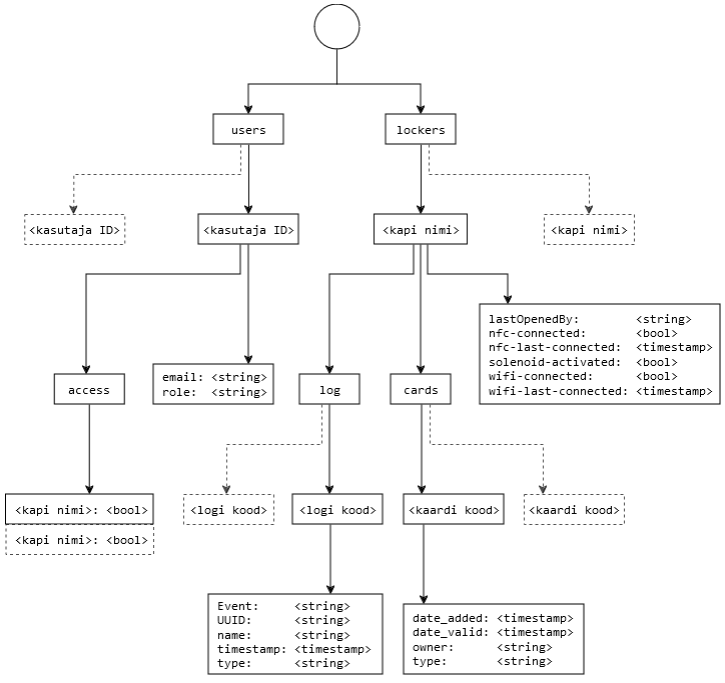
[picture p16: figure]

Joonis 32. JSON formaadis andmemudel.

### 4.1.1 Veebikasutajate haru users

Users väljale saab alluda lõpmatu arv (kuni andmebaas lubab) Firebase’i kasutaja ID-sid.

Unikaalne ID luuakse igale kasutajale Firebase’i autentimissüsteemi poolt automaatselt.

Vastava kasutaja lisamine andmebaasi on aga veebirakenduse vastutada (vt peatükk 4.3).

Igast kasutaja ID-st väljuvad tipud access ning kasutaja e-maili ja rolli hõlmavad nimi-

väärtus paarid. Access tipp on ülemaks lõpmatule hulgale nimi-väärtus paaridele, mis

hoiavad endas vastava kapi nime ja tõeväärtust, määramaksselle, kas kasutajal on ligipääs

vastavale kapile või mitte. Kapinimelise tipu puudumine on võrdväärne ligipääsukeeluga.

### 4.1.2 Kapikasutajate haru lockers

Juurest väljuva lockers alluvateks on lõpmatu hulk tippe kappide nimedega. Nende

tippude nimed peavad olema vastavuses users haru access tipu kirjetega. Rakenduse

töökohalt on oluline, et igal kapil oleks ligipääs ka iseendale (vt peatükk 4.2). Igast

kapinimega tipust väljub kolm tippu – kapi avamisajalugu jälgiv log, kapile ligipääsevate

ISIC kaartide kogu cards ja kapi seisu haldavate omaduste nimi-väärtus paaride kogumik.

Viimane koosneb järgnevatest omadustest: lastOpenedBy, nfc-connected, nfc-last-

connected, solenoid-activated, wifi-connected ja wifi-last-connected. LastOpenedBy

omab väärtusena kaardi omaniku nime, kes viimasena kapi avas. Solenoid-activated on

tõeväärtuslik omadus, mis vastab kapi lukuolekule – kui väärtus on tõene, on solenoid aktiivne ning solenoidluku keel on tõmmatud avatud asendisse. Ülejäänud neli nimi-

väärtus paari vastavad oma ingliskeelse nime järgi, kas Wi-Fi või NFC mooduli

ühendusoleku tõeväärtusele või viimasele ühendushetkele ajatempli näol.

Tipp cards saab omada lõpmata palju unikaalseid kuueteistkümnendsüsteemis olevaid

NFC kaartide koode. Igal kaardikoodiga tipul on alamtipp nelja nimi-väärtus paariga.

Date-added ja date-valid on ajatemplid, mis on vastavalt võrdsed kaardi lisamis- ja

aegumishetkele. Väli owner hoiab endas kaardi omaniku nime. Viimasena on määratud

ka type, mis saab olla kas „teacher“ või „student“. Kui kaardil on üks kahest rollist ning

ajatempel ei viita aegumisele, saab ta kappi avada. „Teacher“ rolliga kaart saab peale

avamise lisada mooduli ekraanilt ka kasutajaid juurde.

Tipust log saab väljuda lõpmata palju unikaalse koodiga alamtippe, igaüks nendest vastab

ühele logisissekandele. Iga logi viitab lehele, kus on viis nimi-väärtus paari. Event hoiab

kirjedust juhtumist – rakendus lisab vaid kirjeldusi Attempted Open ja Opened, mis

vastavad avamiskatsele ja õnnestunud avamisele. UUID väli vastab kaardi koodile, mis

vastava juhtumi põhjustas. Selle väärtus võib olla ka „-“, juhul kui kaardi lugemine

ebaõnnestus või sissekandega on seotud hoopis veebikasutaja. Name väli vastab

veebikasutaja või kaardi omaniku nimele, kui see on teada. Vastasel juhul omandab väli

väärtuse „TBD“. Type on võrdne kasutaja rolliga, tundmatu puhul on väärtuseks

„unknown“. Lisaks on nimi-väärtus paarina veel ajatempel nimega timestamp,

tähistamaks juhtumi ajahetke.

### 4.2 Autentimine ja autoriseerimine

Projekti autentimislahendusena kasutatakse Firebase’i poolt pakutavat Firebase

Authentication teenust. Täpsema seadistusena on määratud autentimispakkujana

„Email/Password“, mille abil saab luua emailipõhiseid parooliga turvatud kasutajaid.

Paroolide turvalise salvestamise ja haldamisega tegeleb Firebase ise automaatselt. Kuigi

kasutajad on meilipõhised, ignoreerib rakendus e-meiliga kasutaja kinnitamist ja

paroolitaastamise funktsiooni, sest kasutajaid peab saama lisada vaid administraator,

mitte potentsiaalne kasutaja ise. See takistab väärkasutajate loomist ning võimalike

turvaaukude ärakasutamist. Kuna email ei lisa kasutajale funktsionaalsust, on

veebiliideses see peidetud ja kuvatud on selle asemel kasutajanimi, mis tegelikkuses

autentimisel ja autoriseerimisel muudetakse emailiks domeenilõpuga „@nutikapp.ee“.

Mitme kapi tugi tekitas vajaduse rollipõhise autoriseerimise järgi, et iga kasutaja ei saaks

iga kapi seadeid muuta ja kasutajaid lisada. Selleks lisati rollid „admin“, „user ja

„locker““ – esimene saab muuta viimaste ligipääsu vastavale kapile. Autoriseerimine on

lahendatud Firebase’i reaalaja andmebaasi reeglitega (vt lisa 2). Need reeglid kehtivad

kõigele ja kõigile, kes üritavad andmebaasile ligi pääseda.

Reeglistik toimib põhimõttel, et kui kellelgi on ülemtipule ligipääs, on tal ligipääs ka

kõikidele tema alamtippudele. Eraldi ligipääsureeglid on kehtestatud kogu lockers

objektile, kindla nimega kapile, kogu users objektile ja kindla nimega kasutajale. Kõik

reeglid on piiratud tingimusega, et autentimine ei tohi puududa, vältimaks väljalogituna

ligipääsemist.

Oli vajalik tagada, et administraatorid saaksid ligi kõikidele kappidele, kasutajad aga

ainult nendele, millele neil on luba antud. Selleks on kirjutamis- ja lugemisõigused kogu

lockers objektile on antud vaid juhul, kui sisselogitud kasutaja roll andmebaasi users

harus on „admin“. Individuaalse kapi lugemis- ja kirjutamisõigused on aga ka antud neile,

kellel on access all alamtipuna nimi-väärtus paarina vastava kapi nimi ja tõeväärtus true.

Oluline oli ka piirata teiste kasutajate ligipääsu kõigi andmetele. Administraatorid aga

vajavad kasutajate loeteluele täieliku ligipääsu, et veebikasutajaid hallata. See realiseeriti

sarnaselt eelnevale - kui users harus on sisselogitud kasutajal „admin“, on tal lugemis-

ja kirjutamisõigus kogu users harus. „User“ või „locker“ tüüpi kasutaja saab vastava kasutaja andmeid lugeda vaid siis, kui päritud kasutaja ID on sama, mis sisselogitud

kasutaja ID.

Selline autoriseerimisskeem tekitas vajaduse lisada kasutajad ka kappidele. Varasemas

projektis pidi kapiseade samuti sisse logima, et andmebaasile ligi pääseda, kuid tegi seda

läbi arendusadministraatori kasutaja. Vältimaks seda, et kapi kaudu saaks kuidagi ligi

kogu andmebaasile, lisati kappide jaoks eraldi roll „lockers“ ja igale kapile oma kasutaja.

Eraldi roll on hea kapile ja tavakasutajatele mõeldud kontode eristamiseks, kuid käitub

sellele lisaks ka veebirakenduses teisti kui roll „user“, kui teda lisada või muuta (vt

peatükk 4.3.5).

### 4.3 Veebirakendus

Veebirakendus on endiselt üles ehitatud raamistikuga Vue.js, mis ehitab üles SPA tüüpi

veebilehe. Vue.js laiendab HTML-i märksõnadega, et elemente saaks TypeScripti

kasutades dünaamiliseks muuta. SPA-le omaselt, kasutab Vue.js router’it, et lehe

uuestilaadimise asemel kuvada URL-ile vastava View ehk vaate sisu dünaamiliselt App

komponendile [13].

Antud edasiarenduse raames tuli täiendada kõiki komponente peale ErrorPage’i. Vanad

view’d vajasid vaid mõne argumendi muutust ja rollikontrolle,neid juhtivad komponendid

aga suuremaid muutusi. Lisati uus view „AdminPage.vue“, navigatsiooniriba

„BasicNavBar.vue“ | ja | juhtkomponendid | „AdminController.ts“ | ning

„HomeController.ts“. Kõiki lisandunud komponente ja nende suhteid ülejäänud

rakendusega on näha komponentdiagrammilt joonisel 33. Järgnevates peatükkides on

lahti seletatud vaid uued komponendid ja tehtud muudatused, varemloodu täpsema

kirjelduse leiab eelneva projekti aruandest [1].

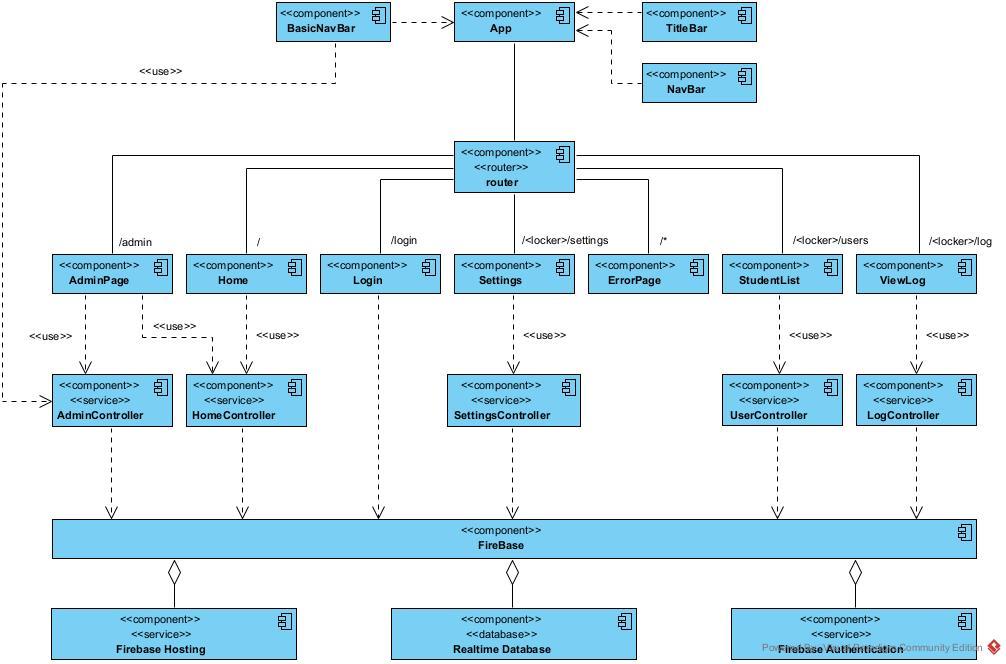
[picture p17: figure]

### 4.3.1 Komponendid router.ts ja app.vue

Et võimaldada mitme kapi tugi, pidi „Router.ts“ muutuma dünaamiliseks. Kindla kapi

seadetele, kasutajatele ja logidele ligipääsemiseks pidi looma igale kapile oma unikaalse

URL-i. Selleks on pandud router võtma vastu kõiki „/settings“, „/logs“ ja „/users“ linke,

enne mida on veel suvalise nimega marsruut. See marsruut muudetakse parameetriks

„lockerName“. Kui kasutaja üritab ligi pääseda seadetele kapil nimega „kapp1“, peab ta

minema lehele „/kapp1/settings“. Lehele minnes annab router vastava parameetri nime

„kapp1“ propina kaasa komponendile, et ta teaks andmebaasist vastavat kappi otsida.

Peale selle on lisatud uus route AdminPage’ile aadressil „/admin“. Seadete, logide ja

kasutajate lehekülgede nimepäisesse on samuti lisatud vastava kapi nimi.

Rakeduse tuumleheküljele „App.vue“ lisandus uus navigatsiooniriba „BasicNavBar.vue“

ja uuendatud tingimused, millist navigatsiooniriba peab rakendus hetkel kuvama.

Lehtedel, mis on seotud individuaalsete kappidega ehk „Settings.vue“, „StudentList.vue“

ja „ViewLog.vue“ kuvadad endiselt „NavBar.vue“ komponenti, mis võimaldab liikuda

eelnevalt nimetatud lehtede vahel. „BasicNavBar.vue“ komponenti, kus seda

funktsionaalsust pole, kasutavad veebilehed aga juhul, mille URL on „/“, „/admin“ või

Joonis 33. Veebirakenduse komponentdiagramm.

lehekülje nimi „NotFound“. Marsruudil „/login“ kasutatakse viideteta riba

„TitleBar.vue“, sest enne sisselogimist ei saa nagunii teistele lehtedele ligi.

### 4.3.2 Navigatsiooniribade komponendid

Mitme kapi toe lisamisel tekkis vajadus uue navigatsiooniriba järele, sest „NavBar.vue“

ei saanud olla enam kõikidel vaadetel. Pea-, administratiiv- ja „Not Found“ lehed on

üleüldised, ega pole seotud ühegi kapiga, seega ei saa nendele lisada viiteid kappide

seadete-, logide- ja kasutajahaldamislehtedele, sest nad ei tea millisele kapile viidata.

Selleks loodi uus navigatsiooniriba „BasicNavBar.vue“, mis on sisuliselt ilma

kapinavigatsioonita | „NavBar.vue“. | Samuti | kasutab | uus | riba | komponendi

„AdminController“ meetodit „getUserRole“, et kuvada viit administratiivlehele juhul kui

kasutaja on administraator (vt joonist 34).

Joonis 34. „BasicNavBar.vue“ administraatori vaates erinevate aknasuuruste puhul

Lisaks muudeti ka vana navigatsiooniriba „NavBar.vue“, kust eemaldati arvutivaates

viide „Kodu“ ja lisati veidi ajakohasem kasutajakogemus klikitava logo näol. Nii telefoni-

kui ka arvutivaatesse lisati viide kapi nimele, et kasutaja teaks, millise kapi seadeid, logi

või kasutajaid ta hetkel näeb (vt joonis 35).

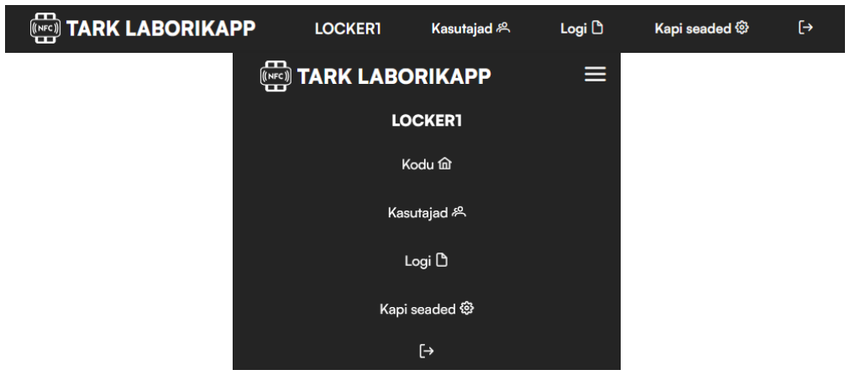
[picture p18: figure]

Joonis 35. „NavBar.vue“ erinevate aknasuuruste puhul.

### 4.3.3 Kapi seadete-, logide- ja kasutajahaldamisvaadete komponendid

Kapi seadeid, logisid ja kasutajaid juhtivates komponentides muutus andmete hankimine.

Iga | meetod | komponentides | „UserController.ts“, | „LogController.ts“ | ja

„SettingsController.ts“, mis lisab või otsib andmebaasist midagi, on saanud juurde

parameetri „lockerName“. Mitme kapi toe tõttu vajavad nende komponentide meetodid

andmebaasist vastava kapi andmete otsimiseks kapi nime. Routeriga kaasa antud prop

„lockerName“ jõuab kõigepealt view’sse ja sealt seejärel antakse ta argumendina edasi

ühele nende komponendi meetoditest.

Peale propi saatmise vastavale meetodile, on lisatud vaatedetesse „StudentList.vue“,

„ViewLog.vue“ ja „Settings.vue“ ka veateated, juhul kui kasutajal pole õigusi kapile ligi

pääsemiseks. Oluline muutus tehti vaatele „StudentList.vue“, kus muudeti kasutaja kaardi

sisestusmalli nõnda, et sinna jääksid tühikute asemel sidekriipsud. Firebase ei luba olemi

nimesse tühikuid panna, see oli ka põhjuseks miks vana kapiseade töötamast lakkas (vt

peatükk 4.4.3). Samuti on lisatud pisikesi mugavus- ja kujundusmuudatusi, näiteks

seadete lehekülje paneelil kuvatakse nüüd ka kapi nimi, eemaldati ebavajalik väli „ukse

olek“, parandati suurusemuutustele reageerimine ja viga, kus nupp „Ava kapp“ muutus

vajutades piklikuks (vt Joonis 36).

### 4.3.4 Pea- ehk koduvaate komponendid

Juurele viitav URL, ehk lehekülje koduvaade „Home.vue“, kuvab kõik kapid ja nende

seadetele, kasutajatele ning logidele suunavad nupud, millele kasutajal ligipääs on.

Varasemalt oli see püsikodeeritud, sest rakenduses oli vaid üks kapp, millele link

suunama pidi. Pealehe dünaamiliseks muutmiseks oli vaja luua juhtkomponent

„HomeController.ts“, mis päriks kasutaja ligipääsuandmeid.

Joonis 36. Settings.vue kapiseadetepaneel.

Meetod „getUserLockers“ võtab parameetrina sisse kasutaja-ID, et leida andmebaasist

vasted kindla users haru access objektist. Iga tõese nimi-väärtus paari korral lisatakse

vastava kapi nimi massiivi ja tagastatakse meetodi kutsujale. Vasteid mitte leides

tagastatakse tühi massiiv.

Meetod „getAllLockers“ on mõeldud vaid administraatorile, sest pärib kogu lockers haru

alamliikmed, millele on ligipääs seadistatud reeglite kohaselt vaid kasutajatel rolliga

„admin“ (vt peatükk 5.2). Meetod otsib andmebaasi lockers harust üles kõikide kappide

nimed ja tagastab need massiivina. Vaade „Home.vue“ kasutab ka komponenti

„AdminController.vue“, et teada saada kasutaja roll ja valida seejärel üks

„HomeController.vue“ meetoditest ligipääsuga kappide hankimiseks. Peale seda lisatakse

iteratiivselt kõik kapid ja nende lingid HTML elementidena leheküljele. Korrektse

kuvamise jaoks on kasutatud CSS grid display tüüpi, mis reageerib ka õigesti vastavalt

internetilehitseja aknasuurusele (vt joonis 37).

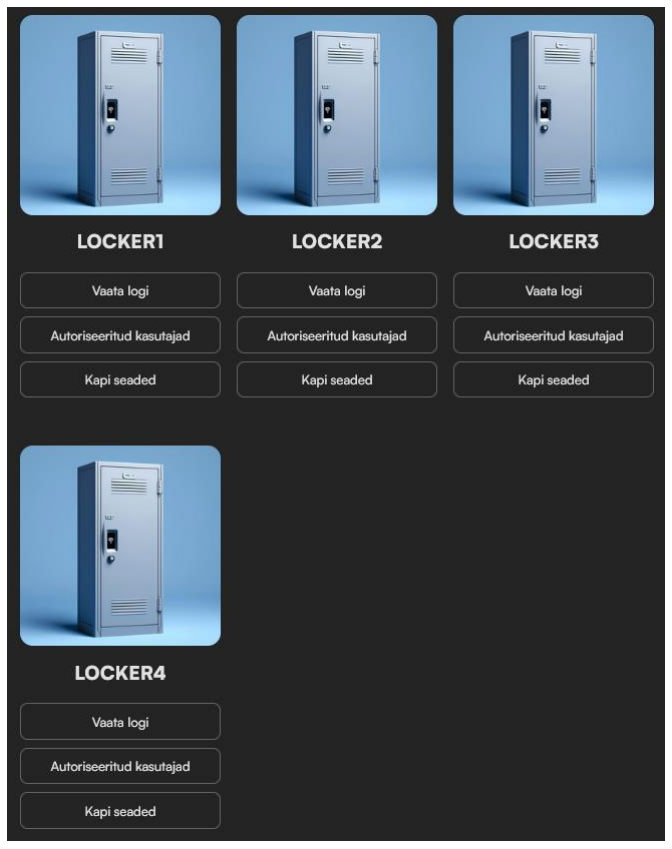
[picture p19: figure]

### 4.3.5 Administratiivvaate komponendid

Mitme kapi tugi tekitas vajaduse kasutajate administreerimise järele. Kuigi kasutajaid

saaks hallata ka lihtsalt andmebaasi kaudu, on palju mugavam teha seda läbi

Joonis 37. „Home.vue“ vaade nelja kapiga.

kasutajaliidese. Selleks lisati rakendusse vaade „AdminPage.vue“ ja komponent

„AdminController.ts“.

Komponent „AdminController.ts“ on kaks meetodit kasutajaandmete hankimiseks.

„getUserRole“ hangib sisse antud kasutaja-ID argumendi alusel vastava kasutaja rolli

andmebaasi users harus. Tavakasutaja saab andmebaasireeglite tõttu hankida vaid enda

rolli, administraator aga kõigi. See meetod on antud komponendis ainuke meetod, mida

saab kasutada ka tavakasutaja. „GetAllUsersAndSort“ hangib kõik kasutajad users harus,

ning võtab lisaks sisse ka parameetrid „sortField“ ja „sortOrder“, et tagastatud tabel

oleks soovitud järjestuses. Sorteerimiseks kasutab ta eraldi komponendi meetodit

„sortTable“.

„AdminController.ts“ komponendis on veel kolm meetodit kasutajate haldamiseks:

„addUser“, „updateUser“ ja „removeUser“. Esimene võtab parameetritena sisse

kasutajanime, parooli, rolli ja ligipääsu kirje, loob kõigepealt Firebase Authenticationi

kaudu uue kasutaja ning seejärel lisab kasutajaandmed ka reaalaja andmebaasi. Meetod

tagastab loodud kasutaja andmed, koos loodud kasutaja ID-ga. Kasutajanimele liidetakse

otsa meilidomeen „@nutikapp.ee“. Uue kasutaja loomiseks Firebase’is tuli kasutada

meetodit „createUserWithEmailAndPassword“, kuid antud meetod logib peale uue

kasutaja loomist kasutaja looja ka sinna kasutajasse sisse. Vältimaks, et administraator

lüüakse peale kasutaja loomist sessioonist välja, mistõttu ei jõua uuele kasutajale vastavad

kirjed andmebaasi users harusse, loodi taustale uus ajutine sessioon, mis loob kasutaja

administraatori eest ja logib kohe ka välja [14]. „UpdateUser“ meetodi kaudu saab

andmebaasis olevaid kasutajaandmeid muuta. „RemoveUser“ kustutab vastava kasutaja

andmebaasist. Küll aga ei eemalda viimane meetod kasutajat Firebase’ist. Turvalisuse

eesmärgil saab rakenduse kaudu oma Firebase’i konto kustutada ainult kasutaja ise.

Seetõttu peab kontode lõpliku kustutamise tegema Firebase’i keskkonnas. Nii „addUser“

kui ka „updateUser“ käituvad vastavalt argumendina saadud rollile erinevalt. Kui

kasutaja rolliks on „locker“, määratakse talle ligipääsetavaks kapiks automaatselt

iseennast ja lisatakse vastavad kirjed uuest kapist ka andmebaasi lockers harusse.

Samamoodi eemaldavad „updateUser“ ja „removeUser“ ebavajalikud andmebaasi kirjed.

„AdminPage.vue“ kuvab olemasolevate kasutajate ID-d, kasutajanimed, rollid ja

ligipääsuandmed tabelis, sarnaselt vaatele „StudentList.vue“ (vt joonis 38). Vaates on

võimalik sorteerida andmeid vastavalt kasutaja ID-le, kasutajanimele ja rollile, klikkides

vastavale kategooriale. Vasakult ülevalt on võimalik uusi kasutajaid lisada. Paremalt saab

vastava kasutaja andmeid muuta, või üldse kustutada. Samuti on võimalik teha

kasutajatest mitmikvalik, et neid korraga kustutada.

Joonisel 39 on kujutatud kasutaja lisamise vaade. Kasutaja lisamis- ja muutmisaken on

sarnased, viimases on peidetud vaid parool ja lukustatud kasutajanime lahter. Kasutaja

rolli muutmine toimib valikuribaga. Vastavalt rollile kuvatakse ka kõige alumine lahter

„Ligipääs“, kust on võimalik hallata kasutaja kappide õiguseid. Kappide valik tekib vaid

„user“ rollil, „locker“ rollil määratakse automaatselt ligipääs iseendale ja „admin“ eraldi

ligipääsu ei saagi, sest antud rollil on ligipääs igalepoole automaatselt.

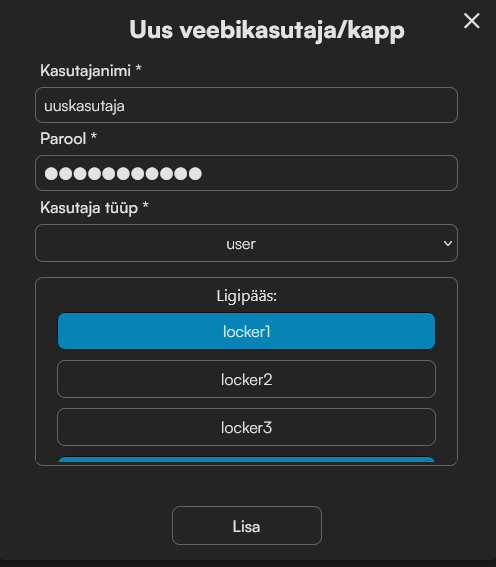
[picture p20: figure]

Joonis 39. AdminPage.vue veebikasutaja lisamise vaade.

Joonis 38. AdminPage.vue tabelivaade.

### 4.4 Püsivara

Püsivara pidi seadistama ümber uuele platvormile ESP32, samuti pidi arvestama teiste

riistvaraliste muutustega, nagu puuteekraan, seadistatud GPIO väljaviigud ja flash mälu

suurus. Oluline samm oli tuvastada ja parandada viga, mis põhjustas vana seadme vigase

töötamise. Püsivaras pidi samuti arvestama mitme kapi toe olemasoluga ja viima sisse

vastavad muudatused, sest ka mikrokontroller vajab ligipääsu andmebaasile.

### 4.4.1 Projekti seadistus

Eelnevad autorid võtsid kasutusele Visual Studio Code’i laienduse PlatformIO, sest see

muudab projekti ülesseadmise mugavamaks [1]. Kuigi valik oli hea, oli ülesseadmine

siiski tülikas, sest nende keskkonna seadetes oli puudusi. Selle asemel, et lisada kasutatud

teegid PlatformIO seadistusse, lisasid nad kasutatud teegid otse koodihoidlasse. See

põhjustab aga olukorra, et teegid ei uuene automaatselt ja nendega ei lisandu teegi

toimimiseks vajalikke kompilaatoriargumente.

Kõik välised teegid eemaldati koodihoidlast ja lisati siis tagasi, kasutades PlatformIO

seadistusfaili „platformio.ini“. Samuti määrati uueks platvormiks MH-ET LIVE ESP32,

et teist mikrokontrollerit kasutada. PlatformIO seadistusse märgiti ka ekraani seaded,

ekraanikontrolleri tüüp ja mikrokontrolleri väljaviigud, vastavalt välisele teegile

„TFT_eSPI“ ja Adafruiti dokumentatsioonile [15] [16]. Teekide täpsemast kasutusest

projektis saab lugeda vana projekti aruandest [1].

Kapi esmase ülesseadmise lihtsustamiseks tulevikus lisati failid „PinConfig.h“ ja

„FirebaseConfig.example.h“. Esimeses on võimalik muuta globaalselt väljaviike

vastavalt vajadusele. Teine aga teeb palju lihtsamaks eelnevate autorite lahenduse

kopeerida vajalik kood Firebase’i seadistamiseks väljaspoolt – fail tuleb lihtsalt

duplikeerida, nimeks panna „FirebaseConfig.h“, ning asendada failis olevad lüngad oma

seadistatava kapi nime, Wi-Fi SSID, parooli, Firebasei API võtme, ühendusstringi ja

kasutajakonto andmetega.

### 4.4.2 Platvormivahetusest tingitud muudatused

Platformivahetusest ja arenduskeskkonna muutumisest tekkis projektis hulk vigu, mida

oli vaja parandada. C++ kompilaatori muutus tekitas vajaduse „FBServer.cpp“ failis

muuta funktsioonide käitumist – objektid pidi looma enne funktsiooni kasutamist ja nende aadressid andma sisse argumendina, sest funktsiooni kaudu väärtuse tagastamine

ei toiminud. Platvormimuutuse tõttu asendati viited Arduino „ESP8266WiFi.h“ teegile,

mille asemel võeti kasutusele sisseehitatud „WiFi.h“. Programmist eemaldati ka kõik, mis

oli mõeldud magnetsensorile, sest seda ei kasutatud.

### 4.4.3 Vana kapiprojekti vigade parandus

Püsivaras oli kõige olulisem üles leida viga, mis põhjustas vana kapiprojekti töötamise

lakkamise. NFC mooduliga kaardi skännimisel osutus, et Firebase’i päringud ei lähe läbi

ja tagastatakse „Access denied“. Koodi uurimisel ja katsetamisel selgus, et päringud

lähevad läbi vaid siis kui päritavas koodis pole tühikuid. Nõnda muudetigi andmebaasis,

püsivaras ja veebirakenduses ümber kõik kohad, kus kasutati kaardikoodi. Tühikute

asemel võeti kasutusele sidekriipsud, et säilitada loetavus. „Nfc.cpp“ olevas funktsioonis

„convertToString“ liideti iga kahe kuueteistkümnendkujulise järel „-“, sellega oligi

probleem lahendatud.

### 4.4.4 Mitmetuumaline lahendus

Kõige suurem muutus, mis oli vaja püsivarasse sisse viia, oli kahe mikrokontrolleri koodi

viimine ühe kontrolleri kahe tuuma peale. Selleks kasutati FreeRTOS reaalaja

operatsioonisüsteemi, mis haldab kahe tuuma käitumist automaatselt [17].

Ust juhtiv programmiosa otsustati panna tuumale 1, ekraani juhtiv osa tuumale 0.

Programmi alusfaili „main.cpp“ tuli lisada TaskHandle_t tüüpi muutuja, millele

„setup()“ osas määratakse funktsiooniga „xTaskCreatePinnedToCore“ ülesanne, mida

antud muutuja jälgima peab. Antud funktsioonis määratakse ära ka ülesande prioriteet,

pinu suurus ja tuum, millel ta täidetakse. Kuna varasema töö koodid olid hästi eraldatud,

sai suure vaevata luua igaveses tsüklis oleva funktsiooni „DoorController“, mis hõlmas

endas varasema projekti „master“ haru „main“ osa. Tavalisse loop funktsiooni lisati aga

„display“ haru „main“ kood, mis automaatselt jookseb tuumal 0. Kuna vana projekti

ekraanikood oli kõik ühes failis, loodi failid „lockerDisplay.cpp“ ja „lockerDisplay.h“,

kuhu tõsteti kõik ekraanikoodi meetodid, et jätta „main.cpp“ võimalikult selgeks.

Tuumadevaheliseks suhtluseks kasutati FreeRTOSi tüüpi QueueHandle_t ning

meetodeid „xQueueSend“ ja „xQueueReceive“. Igas kohas programmis, kus toimus

„HardwareSerialiga“ jadaandmeside läbi RX ja TX viikude, asendati see suhtlusviis

ühega kahest meetodist vastavalt sellele, kas andmeid saadetakse või kuulatakse. Kui üks tuum tahab teisega suhelda, peab ta vastava sõnumi järjekorda panema. Kuna sõnumi

kuulamised on tsüklilised ja pidevad, siis ei ole vaja interrupti kasutada, sõnum saadakse

teisel pool nagunii peagi kätte. Põhimõttelt jäi suhtlus samasuguseks – ainuke erinevus

on see, et nüüd suhtlevad omavahel tuumad, mitte mikrokontrollerid.

## 5 Mooduli paigaldamise juhend

Targa laborikapi moodul on disainitud nii, et enne toote kliendile andmist, tuleb tootjal

osad detailid kokku panna. Kliendi ülesandeks jääb aga toote edasine paigaldus kapile.

Käesoleva peatüki esimene alapeatükk kirjeldab tootja vaatepunktist komponente, mis

tuleb eelnevalt kokku panna ja kliendile anda ning teine alapeatükk kirjeldab kliendile

antavaid juhiseid mooduli lõplikuks paigaldamiseks.

### 5.1 Kliendile antavad komponendid

Lõpliku tootena antakse kliendile kolm valmis komponenti: välimine korpus koos Gerd

Kanteriga, kinnitusdetailid Elektroonikakarbi, kapi hoovasüsteemi ja Ekraanikorpuse

omavaheliseks kinnitamiseks ning Elektroonikakarp.

### 5.1.1 Välimine korpus koos Gerd Kanteriga

Ekraanikorpusesse peavad olema eelnevalt paigaldatud ekraanimoodul ning NFC moodul

koos vajalike juhtmetega. Korpusel peab olema kaas kruvidega kinnitatud ning 15 viiguga

juhe tuleb läbi kaane ja Kimalase vahel oleva ava. Kuna 15 viiguline pistik ise avast läbi

ei mahu, tuleb juhe sealt läbi vedada enne kaane kinnitamist. Joonisel 40 on näha

juhtmeava lõplikul moodulil ning prototüüpi koos juhtmega.

Joonis 40. Ava Ekraanikorpusest tulevate juhtmete jaoks ning prototüüp koos juhtmega.

Lisaks peab Ekraanikorpusesse olema paigaldatud Kimalane kahe M3 suuruses kruvi või

poldiga ning Käepide koos Toru, postkastilukuga ja sellest tuleva pika poldiga, kuid ilma

poldi otsa käiva keeleta. Käepideme otsa on kinnitatud ka Gerd Kanter koos kahe M3

kruvi või poldiga, tänu millele ongi võimalik anda kliendile toode nii, et Käepide oleks

kohe mooduli küljes. Joonisel 41 on näha prototüübiks kasutuses olnud käepidet koos

postkastiluku, pika poldi ja Gerd Kanteriga ning mooduli välimist korpust koos Kaane,

Kimalase ja Gerd Kanteriga.

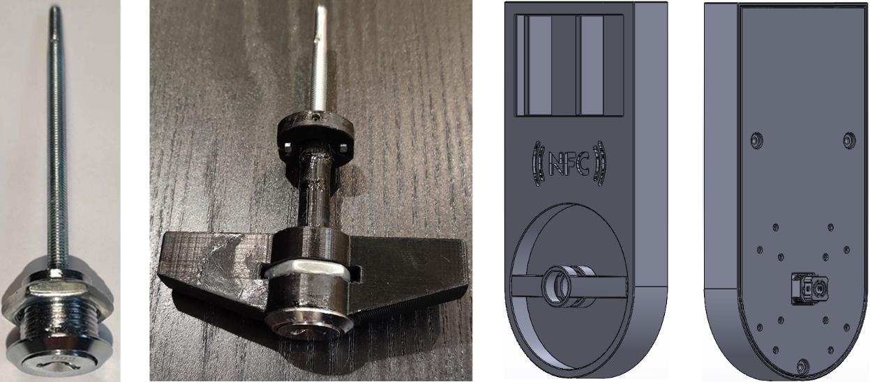
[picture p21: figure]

Joonis 41. Prototüübiks kasutuses olnud Käepide ja esimese valmis komponendi jaoks vajalikud detailid.

### 5.1.2 Kinnitusdetailid

Kinnitusdetailidena antakse kliendile IKEA Laud, Hoidik, Naagelvärk, Mutter, üks

ligikaudu 9 mm pikkune M3 kruvi või polt Naagelvärgi kinnitamiseks Hoidiku külge ja

kümme M3x16 mm polti, millest kahte kasutatakse Hoidiku kinnitamiseks Gerd Kanteri

külge, nelja Elektroonikakarbi kinnitamiseks IKEA Laua külge ning viimaseid keeratakse

vajadusel Tuulerõugetesse. Need detailid ei pea olema kuidagi ette valmistatud, vaid neid

kasutab klient nutikapi mooduli paigaldamiseks. Joonisel 42 on näha vajalikud

kinnitusvahendid.

Joonis 42. Kinnitusvahendid targa laborikapi mooduli paigaldamiseks.

### 5.1.3 Elektroonikakarp

Elektroonikakarpi peab olema eelnevalt paigaldatud solenoid ja kogu mooduli tööks

vajaminev elektroonika v.a ekraanimoodul ja NFC moodul. Solenoid peab olema kahe

kruviga karbi küljes kinni, Elektroonikakarbi Kaas peab olema kinnitatud nelja M3 või

M3.5 kruviga ning 12 V emane toitepistik ja 15 viiguga emane ekraani ning NFC pistik

peavad olema toodud Elektroonikakarbi küljel oleva auguni. Joonisel 43 on näha

modelleeritud detaile kolmanda valmis komponendi jaoks ja pistikuid Elektroonikakarbi

küljel.

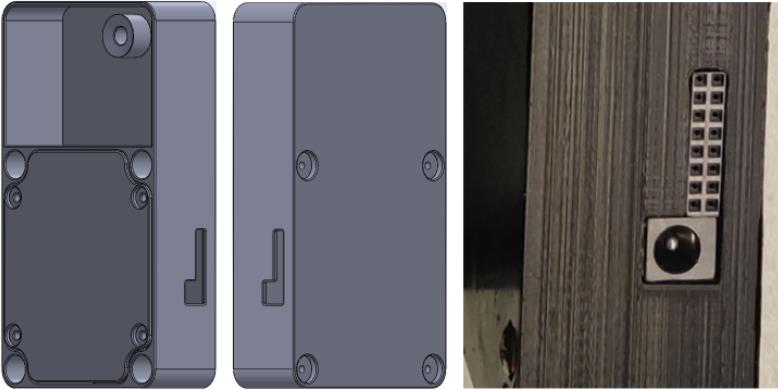
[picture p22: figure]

Joonis 43. Detailid kolmanda valmis komponendi jaoks ning pistikud Elektroonikakarbi küljel.

### 5.2 Mooduli paigaldamine kapile

Esimene sammuna mooduli paigaldamisel tuleb ukselt küljest võtta käepide ning

hoovasüsteem. Originaalsest süsteemist tuleb alles jätta kogu hoovasüsteem ja kapi ukse

keel. Kuigi iga laborikapi ukse avamise mehhanismid on natuke erinevad, on ühte kappi

näha joonisel 44.

Joonis 44. Näidis laborikapist eemaldatavatest detailidest ja järele jääv ava.

Peale ebavajalike detailide eemaldamist jääb kapi uksel nähtavale ava, läbi mille oli

originaalne käepide paigaldatud. Sellest august tuleb läbi panna Kimalane, mis on

eelnevalt kinnitatud välimise korpuse külge. Laborikapi ustes olevad avad võivad kuju ja

suuruse poolest märgatavalt erineda. Hetkel on nutimooduli Kimalase horisontaalne läbimõõt ligikaudu 16 mm ning ta sobitub ühe testitud laborikapi külge. Probleem tekkis

aga joonisel 44 olevale laborikapile mooduli paigaldamisel, kuna ukse ava horisontaalne

läbimõõt on üle 71 mm.

Selleks, et targa laborikapi avamise mehhanism toimiks, on oluline, et moodul oleks

paigaldatud ukse ava keskpunkti, kuna muidu ei ulatu kapi originaalsed riivid üles ja alla

serva ning ei saa ust kinni hoida. Probleemi lahenduseks modelleeriti Ekraanikorpusele,

Ekraanikorpuse Kaanele ja IKEA Lauale Tuulerõuged. Nende abil on võimalik keerata

kapi seest Ekraanikorpusesse M3x16 mm poldid, mis toimivad tugipunktidena ning ei

lase moodulil ukse küljes vertikaalselt ega horisontaalselt liikuda. Joonisel 45 on sinisega

märgitud need Tuulerõuged, mis sobivad kokku joonisel 44 oleva laborikapi avaga. Ülejäänud neist aga võimaldavad moodulit paigaldada ka mõnele muud tüüpi

laborikapile, mille peal prototüüpi pole testitud.

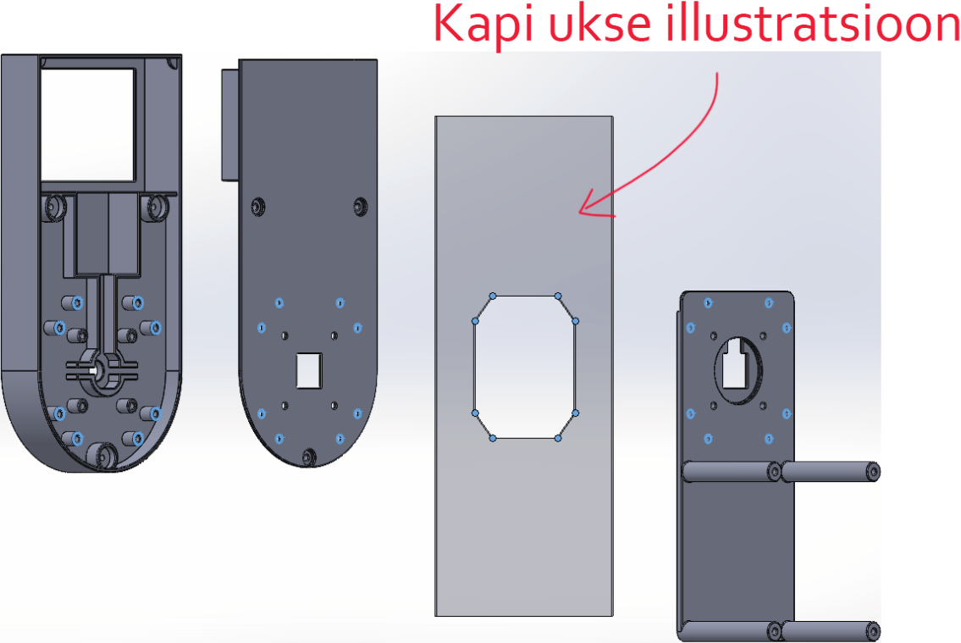
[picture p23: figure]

Joonis 45. Ühe testitud laborikapi jaoks vajaminevad Tuulerõuged mooduli stabiliseerimiseks.

Teise sammuna tuleb panna Kimalase otsa uksest sissepoole IKEA Laud ning keerata see

Mutriga tugevalt ukse külge. See tegevus on kujutatud joonisel 46.

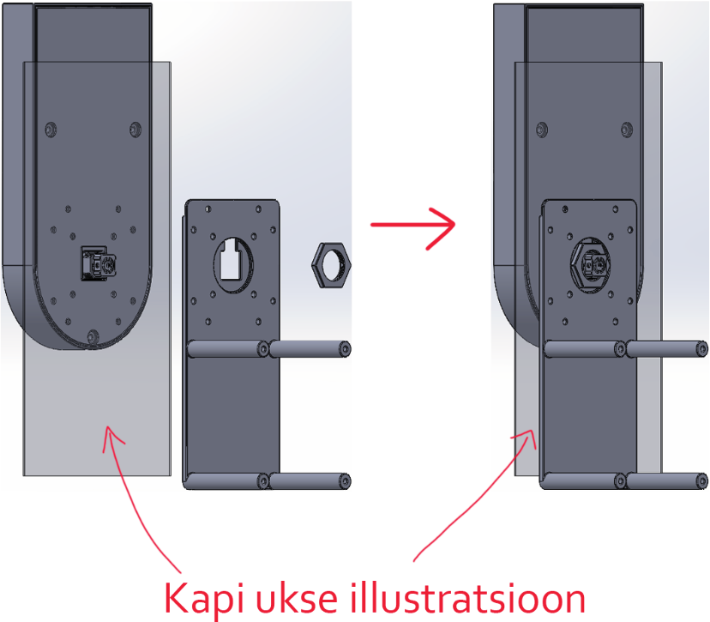
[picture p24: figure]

Joonis 46. Välimise korpuse kinnitamine laborikapi ukse külge.

Kolmandaks kinnitub Gerd Kanteri otsa kahe M3x16 mm poldiga Hoidik ning Hoidiku

otsa ligikaudu 9 mm pikkuse poldiga Naagelvärk (vt Joonis 47).

Joonis 47. Hoidiku ja Naagelvärgi kinnitamine Gerd Kanteri külge.

Neljandaks tuleb kinnitada Käepideme poldi süvendisse postkastiluku keele komponent

ning suunata see Elektroonikakarbis asuvasse tugipunkti nii, et keel jääb allapoole (vt

Joonis 48).

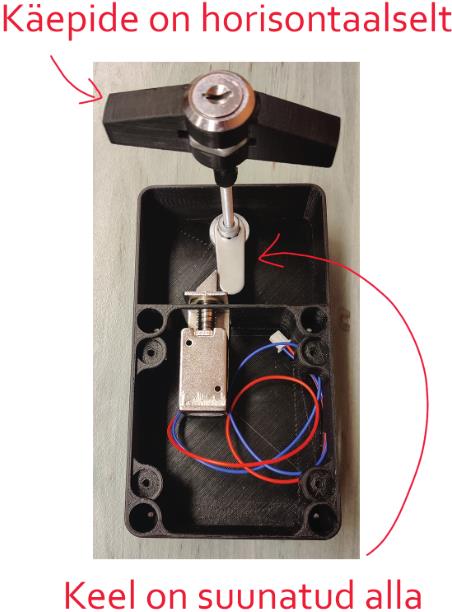
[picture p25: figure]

Joonis 48. Käepideme ja keele asendid Elektroonikakarbis.

Viies samm on Elektroonikakarbi keeramine nelja poldiga IKEA Laua külge ja juhtmete

ühendamine karbi pistikutesse. Lõplikult paigaldatud targa laborikapi moodulit on näha

joonisel 49.

Joonis 49. Lõplikult paigaldatud targa laborikapi moodul.

## 6 Edasiarenduse võimalused

Antud projekti saab edasi arendada mitmel erineval viisil. Projekti autoritel jäid töö

käigus mõned olulised asjad tähelepanuta ja ajanappuse tõttu ei olnud kõike võimalik

paremaks teha.

Kuna prototüüp on valdavas osas plastikust, siis järgmine samm olekski reaalselt mõned

detailid metallist toota ja proovida neid katsetada mõnel laborikapil. Hetkel on polt,

võllikrae, nelinurkne mutter, postkastiluku keel ja seib ostetud ehitusmaterjalide poest

ning vastavalt vajadusele saetud, lihvitud ja kokku liimitud. Kõik need detailid võiksid

olla aga modelleeritud ühe komponendina, et seda oleks lihtsam toota. Küll aga tuleks

kindlasti üle veenduda, et mudelite mõõtmed on ikka korrektsed ning samuti tuleks

uurida, kas praegustele lõpliku mooduli detailidele on keermed õigesti modelleeritud.

Riistvara koha pealt saaks suurema osa elektroonika jaoks trükkplaadi luua selle asemel,

et joodetavale makettplaadile kõik joota. Trükkplaat on kompaktsem, töökindlam ja võtab

ka vähem ruumi mooduli Elektroonikakarbi sees.

Selleks, et lahendus oleks rohkem nagu toode, tuleks tarkvara arendada edasi nii, et Wi-

Fi ühendust, Firebase’i andmebaasi ühendusstringe ja API võtmeid kui ka kapi

kasutajakontot saaks lisada läbi ekraani. Töös saadud lahendus on hardcoded ja eelnevalt

nimetatud tegevusi ei saa teha.

## 7 Kokkuvõte

Töö eesmärk oli ehitada võimalikult kompaktne, soodne, universaalne ja lihtsasti

paigaldatav moodul, mis muudaks metallist laborikapi targaks. Tarkvara pidi võimaldama

ka mitme kapi kasutust. Lahendus pidi kasutama ka kapi originaalset riivi ja voolu

kadumisel pidi kapp olema avatav ka võtmega. Eesmärk oli muuta ka kapp jälle kaardiga

avatavaks.

Peaaegu kõik projektile seatud eesmärgid saadi täidetud ning lõpuks valmis kompaktne

ühe mooduliga piirduv süsteem, mis ei ole kuigi kulukas ja on suhteliselt universaalne

ehk see on paigaldatav erinevatele Tallinna Tehnikaülikooli laborikappidele. Tänu

mooduli kompaktsusele on see ka kergesti paigaldatav. Veebirakendus toetab mitme kapi

kasutust ning eelmise projekti probleem, et kappi ei saanud enam ühel hetkel kaardiga

avada, on samuti lahendatud. Lõplik moodul kasutab kapi algset riivi ja ühtlasi on seda

võimalik avada võtmega. Küll aga loodud laborikapp ei ole autorite definitsiooni järgi

tark. Autorid on defineerinud targa laborikapi kapina, mida on võimalik avada ISIC

kaardiga ning kuhu saab lisada kasutajaid mooduli ekraani kaudu ja läbi

internetirakenduse. Praegusel juhul aga lõppmoodulil ekraani testitud ei ole, seega

laborikappi, millele moodul on paigaldatud, targaks nimetada ei saa.

## Kasutatud kirjandus

[1] M. Visnapuu, R. Randmäe, S. Tišler ja M. Veersoo, „Nutikas laborikapp,“ GitHub, 2023. [Võrgumaterjal]. Available: https://github.com/siimtishler/kapp. [Kasutatud september 2024].
[2] V. Abrol, „digittrix,“ 4 oktoober 2024. [Võrgumaterjal]. Available: https://www.digittrix.com/blogs/nfc-why-nfc-is-popular-and-why-everyone-tries-to-use-it. [Kasutatud detsember 2024].
[3] S. Maestre, „Circuitbread,“ 17 juuni 2021. [Võrgumaterjal]. Available: https://www.circuitbread.com/ee-faq/how-does-a-flyback-diode-work. [Kasutatud november 2024].
[4] Marla, „electronics.stackexchange,“ 15 Mai 2014. [Võrgumaterjal]. Available: https://electronics.stackexchange.com/questions/110574/how-to-choose-a-flyback-diode-for-a-relay. [Kasutatud november 2024].
[5] Diodes Incorporated, „alldatasheet,“ [Võrgumaterjal]. Available: https://www.alldatasheet.com/datasheet-pdf/view/59328/DIODES/SR303.html. [Kasutatud november 2024].
[6] „einstronic,“ [Võrgumaterjal]. Available: https://einstronic.com/product/1-channel-5v-relay-module-ky-019/. [Kasutatud november 2024].
[7] Admin, „how2electronics,“ 29 mai 2023. [Võrgumaterjal]. Available: https://how2electronics.com/interfacing-pn532-nfc-rfid-module-with-arduino/. [Kasutatud oktoober 2024].
[8] G. Schorcht, „doc.riot-os,“ [Võrgumaterjal]. Available: https://doc.riot-os.org/group__boards__esp32__mh-et-live-minikit.html. [Kasutatud oktoober 2024].
[9] M.-W. lady ada, „learn.adafruit,“ 19 august 2014. [Võrgumaterjal]. Available: https://learn.adafruit.com/adafruit-3-5-color-320x480-tft-touchscreen-breakout/spi-wiring-and-test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. [Kasutatud detsember 2024].
[10] Ava, „Unveiling the Difference Between ESP32 and ESP8266,“ Ersa Electronics, [Võrgumaterjal]. Available: https://www.ersaelectronics.com/blog/unveiling-the-difference-between-esp32-and-esp8266.
[11] Google, „Developer documentation for Firebase,“ Firebase, 2024. [Võrgumaterjal]. Available: https://firebase.google.com/docs. [Kasutatud november 2024].
[12] ChatGPT-4o. (2024), OpenAI, [Võrgumaterjal]. Available: https://chat.openai.com. [Kasutatud november 2024].
[13] E. You, „Vue.js Guide,“ Vue.js, 2024. [Võrgumaterjal]. Available: https://vuejs.org/guide. [Kasutatud november 2024].
[14] A. Kool, „Firebase kicks out current user,“ Stack Overflow, 24 juuni 2016. [Võrgumaterjal]. Available:

https://stackoverflow.com/questions/37517208/firebase-kicks-out-current-user/38013551#38013551. [Kasutatud november 2024].
[15] Bodmer, „TFT_eSPI,“ GitHub, 2024. [Võrgumaterjal]. Available: https://github.com/Bodmer/TFT_eSPI. [Kasutatud november 2024].
[16] Adafruit, „3.5" TFT 320x480 + Touchscreen Breakout Board w/MicroSD Socket,“ Adafruit, 2024. [Võrgumaterjal]. Available: https://www.adafruit.com/product/2050. [Kasutatud november 2024].
[17] Amazon Web Services, „FreeRTOS Kernel Developer Docs,“ FreeRTOS, 2024. [Võrgumaterjal]. Available: https://freertos.org/Documentation/02-Kernel/02-Kernel-features/00-Developer-docs. [Kasutatud november 2024].

## Lisa 1 – Link koodihoidlale ja veebilehele

- Koodihoidla GitHubis: https://github.com/krikaa/kappV2
- Demoveebileht: https://nutikapp-v2.web.app
- Kasutajanimi: demo, parool: nutikapp

## Lisa 2 – Reaalaja andmebaasi turvareeglid

{
"rules": {
"lockers": {
".read": "auth != null &&
root.child('users').child(auth.uid) .child('role').val() === 'admin'", ".write": "auth != null && root.child('users').child(auth.uid). child('role').val() === 'admin'",
"$lockerName": {
".read": "auth != null &&
root.child('users').child(auth.uid).child('access') .child($lockerName).val() === true",
".write": "auth != null && root.child('users').child(auth.uid).child('access') .child($lockerName).val() === true",
}
},
"users": {
".read": "auth != null &&
root.child('users').child(auth.uid) .child('role').val() === 'admin'", ".write": "auth != null && root.child('users').child(auth.uid) .child('role').val() === 'admin'", "$user_id": {
".read": "auth != null && auth.uid === $user_id", }
}
}
}

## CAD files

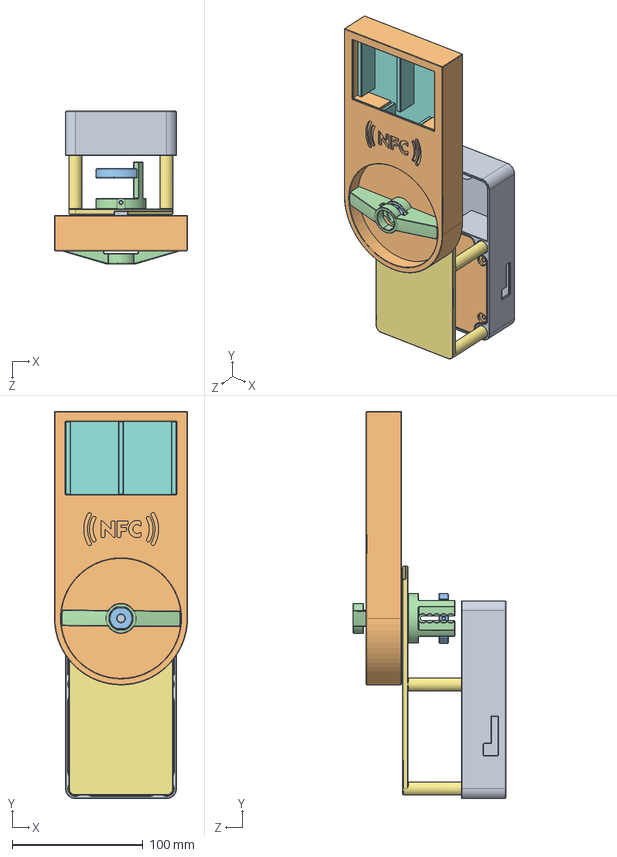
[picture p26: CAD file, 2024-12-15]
3D-models/Targa laborikapi detailid kokkupanduna.SLDASM
102.0 x 296.5 x 117.0 mm
Käepide
Toru
Ekraanikorpus
Kimalane
Ekraanikorpuse Kaas
IKEA Laud
Gerd Kanter
Mutter
Hoidik
Naagelvärk
Elektroonikakarbi kaas
Elektroonikakarp

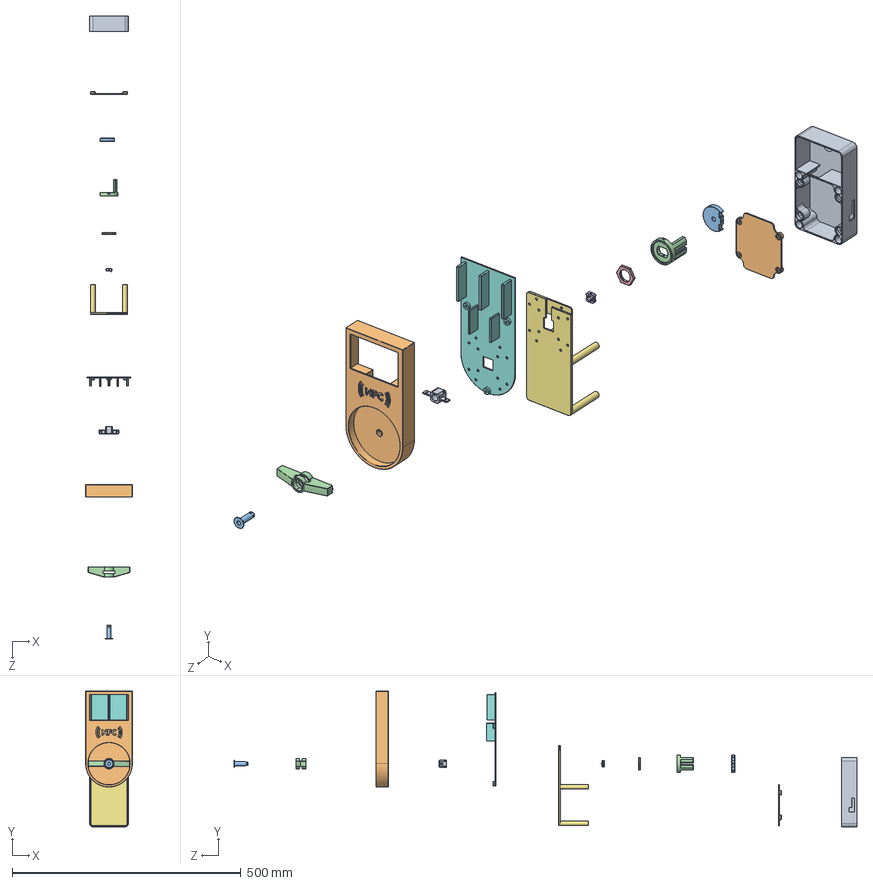
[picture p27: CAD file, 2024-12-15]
3D-models/Targa laborikapi detailid eraldatuna.SLDASM
102.0 x 296.5 x 1360.6 mm
Käepide
Toru
Ekraanikorpus
Kimalane
Ekraanikorpuse Kaas
IKEA Laud
Gerd Kanter
Mutter
Hoidik
Naagelvärk
Elektroonikakarbi kaas
Elektroonikakarp

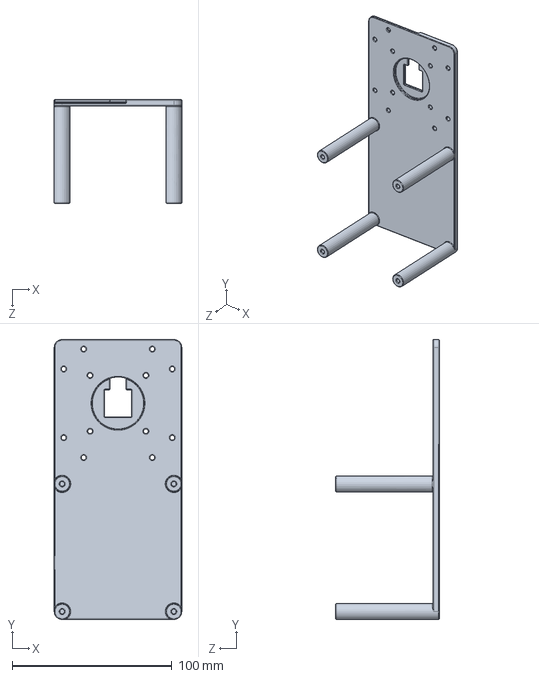
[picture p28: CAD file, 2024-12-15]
3D-models/IKEA Laud.SLDPRT
80.0 x 175.5 x 65.0 mm

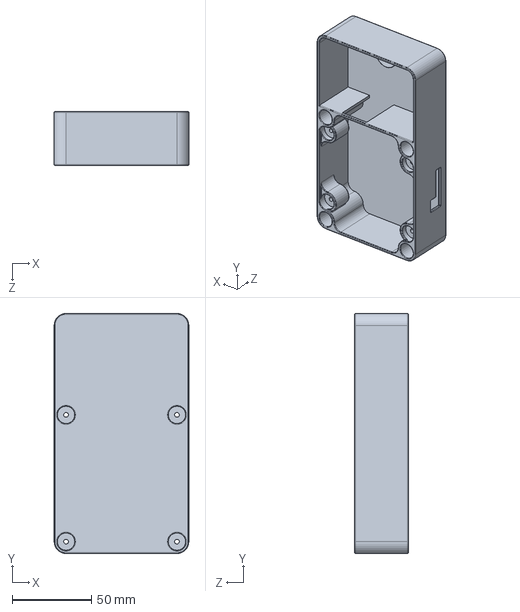
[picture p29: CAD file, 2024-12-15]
3D-models/Elektroonikakarp.SLDPRT
85.0 x 151.5 x 34.0 mm

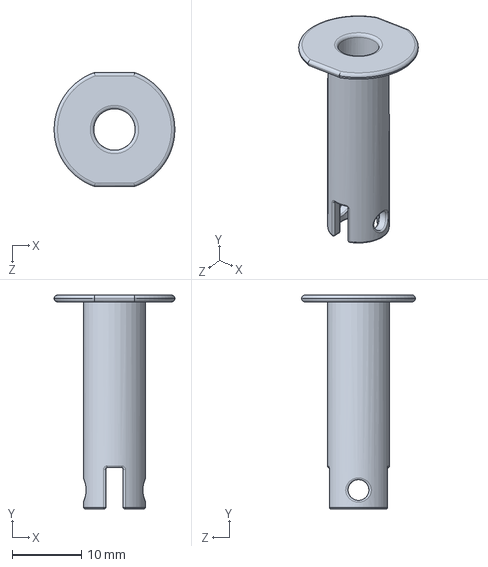
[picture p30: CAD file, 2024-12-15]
3D-models/Toru.SLDPRT
17.5 x 31.0 x 16.5 mm

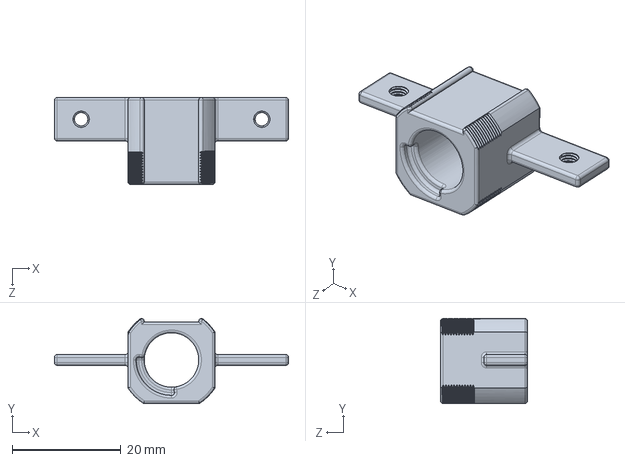
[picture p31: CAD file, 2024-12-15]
3D-models/Kimalane.SLDPRT
43.0 x 15.6 x 16.0 mm

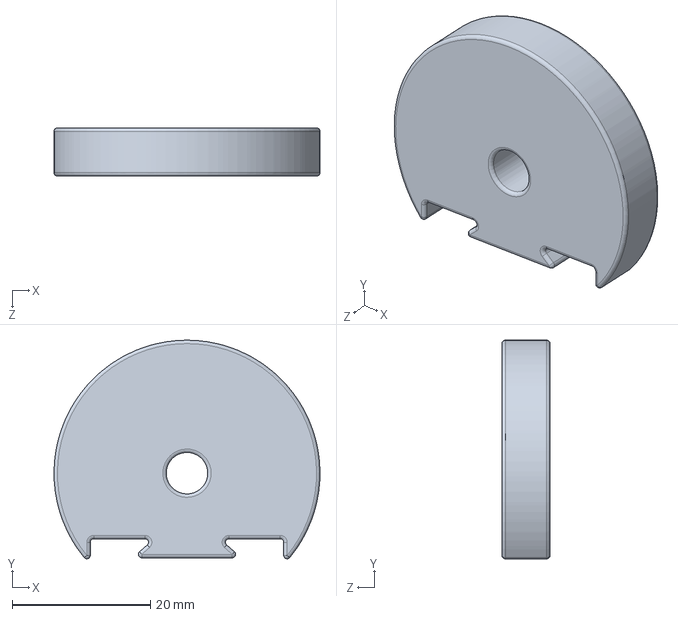
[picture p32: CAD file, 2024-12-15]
3D-models/Naagelvärk.SLDPRT
38.5 x 31.6 x 7.00 mm

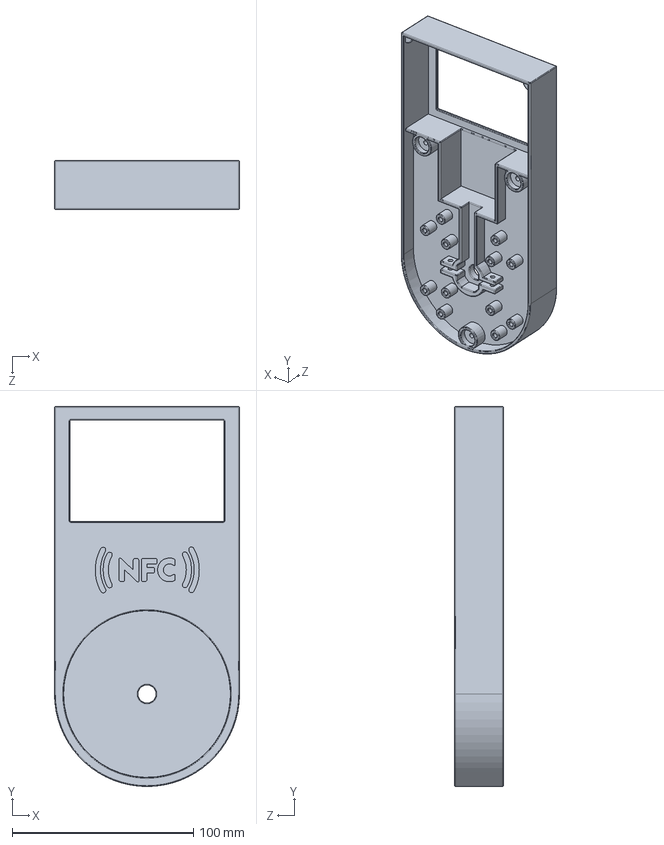
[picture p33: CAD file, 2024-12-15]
3D-models/Ekraanikorpus.SLDPRT
102.0 x 209.5 x 27.0 mm

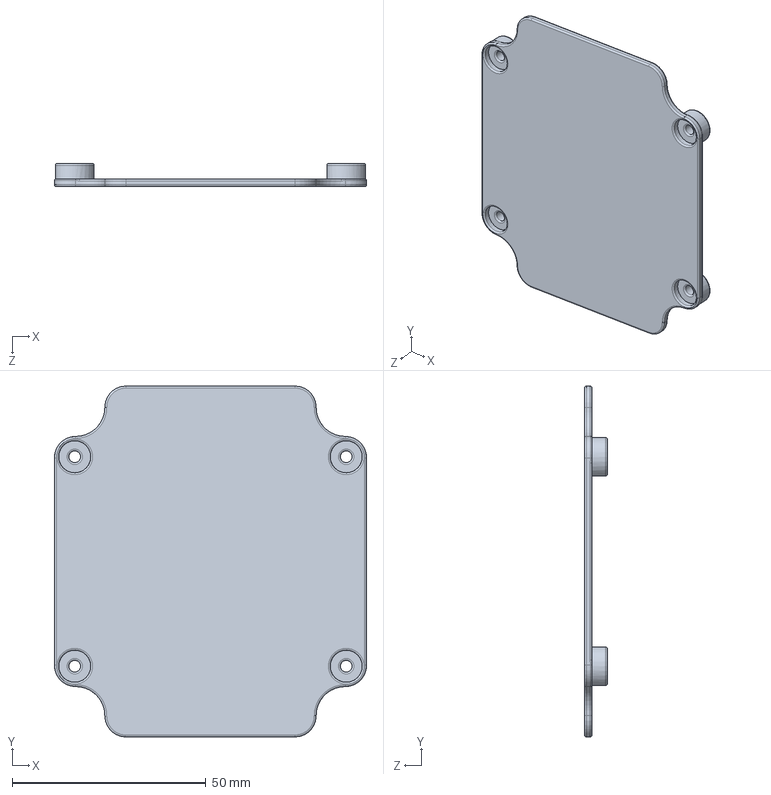
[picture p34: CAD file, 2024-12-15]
3D-models/Elektroonikakarbi Kaas.SLDPRT
80.5 x 90.5 x 6.00 mm

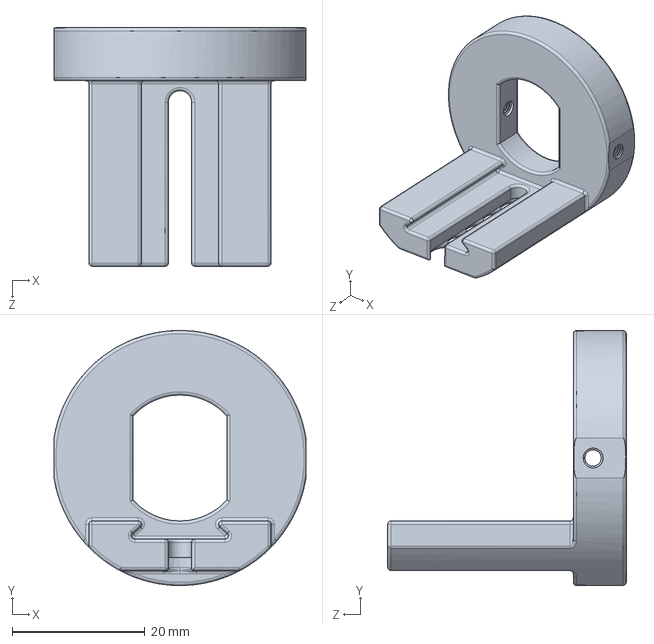
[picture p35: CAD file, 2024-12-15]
3D-models/Hoidik.SLDPRT
38.0 x 38.5 x 36.0 mm

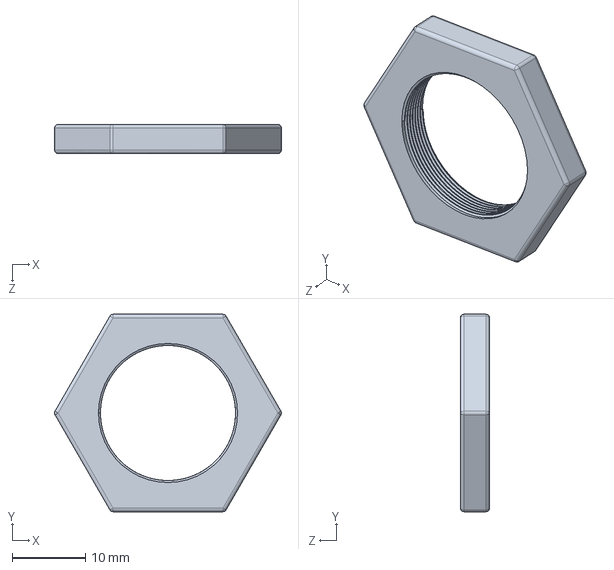
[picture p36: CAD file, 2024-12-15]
3D-models/Mutter.SLDPRT
31.0 x 27.0 x 4.00 mm

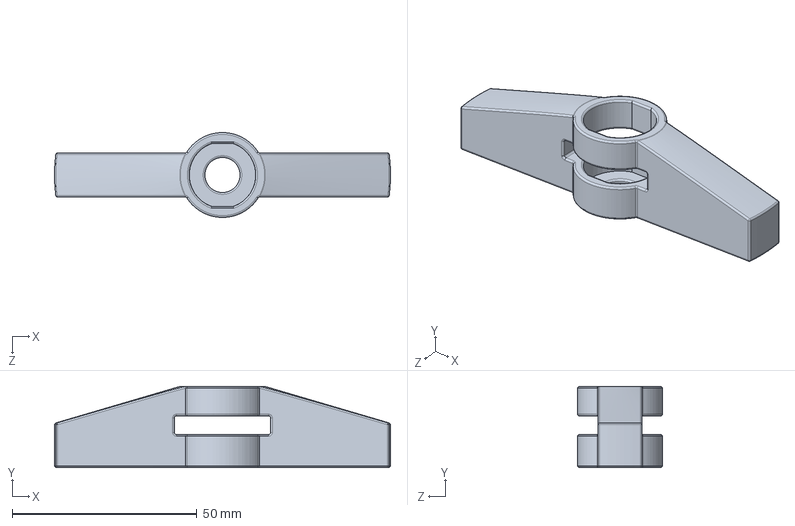
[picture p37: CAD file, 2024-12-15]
3D-models/Käepide.SLDPRT
91.0 x 22.0 x 23.0 mm

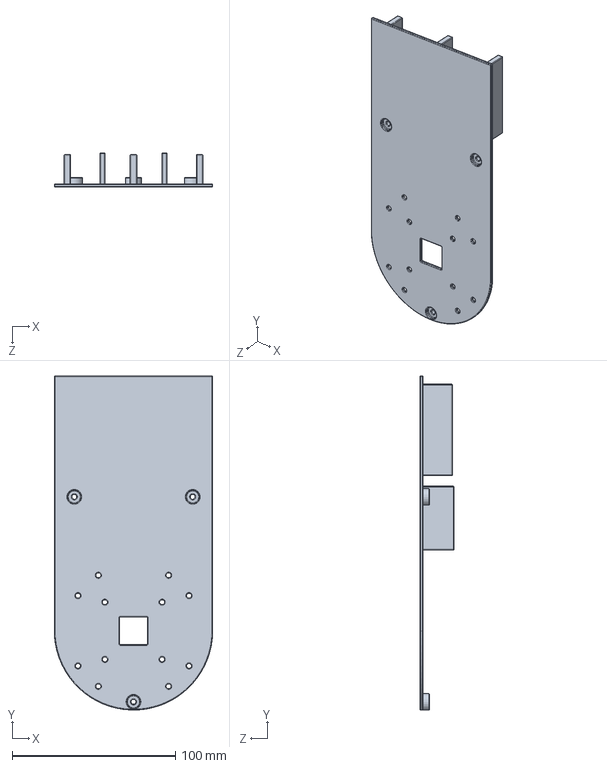
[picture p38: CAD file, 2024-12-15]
3D-models/Ekraanikorpuse Kaas.SLDPRT
97.0 x 204.5 x 21.0 mm

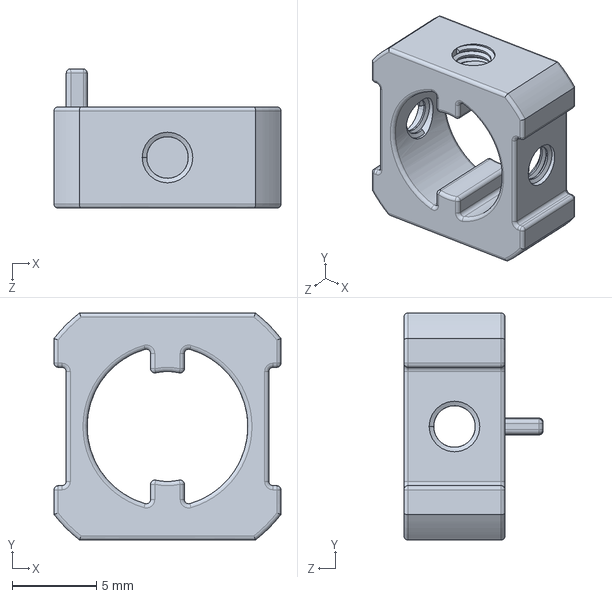
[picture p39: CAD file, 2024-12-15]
3D-models/Gerd Kanter.SLDPRT
13.4 x 13.4 x 8.25 mm

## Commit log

2023-11-30 UART comm working"
2023-12-21 3D file
    [Laborikapp-ekraan-v1.stl]
2024-10-05 Emptying repository to create submodules
    [Korpus V02.SLDPRT, Korpuse kaas.SLDPRT, Laborikapp-ekraan-v1.stl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]
2024-10-05 Added general project files to main repository
    [Korpus V02.SLDPRT, Korpuse kaas.SLDPRT, Laborikapp-ekraan-v1.stl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]
2024-12-10 Added documentation, schematic, removed old model files
    [Korpus V02.SLDPRT, Korpuse kaas.SLDPRT, Laborikapp-ekraan-v1.stl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]
2024-12-15 Added 3D-models to the repository
    [Ekraanikorpus.SLDPRT, Ekraanikorpuse Kaas.SLDPRT, Elektroonikakarbi kaas.SLDPRT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]
2024-12-15 Renamed SLDPRT "Elektroonikakarbi kaas", updated readme
    [Elektroonikakarbi Kaas.SLDPRT]
